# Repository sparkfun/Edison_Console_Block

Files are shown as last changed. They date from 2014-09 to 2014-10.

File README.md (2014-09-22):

Console
=====================

The Console expansion board delivers power to the Intel Edison while providing a simple console interface.  This is a minimal solution to get started using the Intel Edison.  The Console board can supply 4V and up to 1.5A of current to power the Edison and any other expansion boards you may add to your stack. This power is passed through the VSYS line of the Edison.

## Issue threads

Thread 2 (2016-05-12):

Where can I find BOM

Tondy, 2016-05-12:
Hello

Is the Bill of materials available on the github?

ToniCorinne, 2016-05-12:
We are not currently including BOMs as separate files in our repositories, though this is something we are looking into. Currently, you'd need to run the bom.ulp on the Eagle files to export the BOM. For more information on working with Eagle files, check out our tutorials [here](https://learn.sparkfun.com/tutorials/tags/eagle).

Closed 2016-05-12.

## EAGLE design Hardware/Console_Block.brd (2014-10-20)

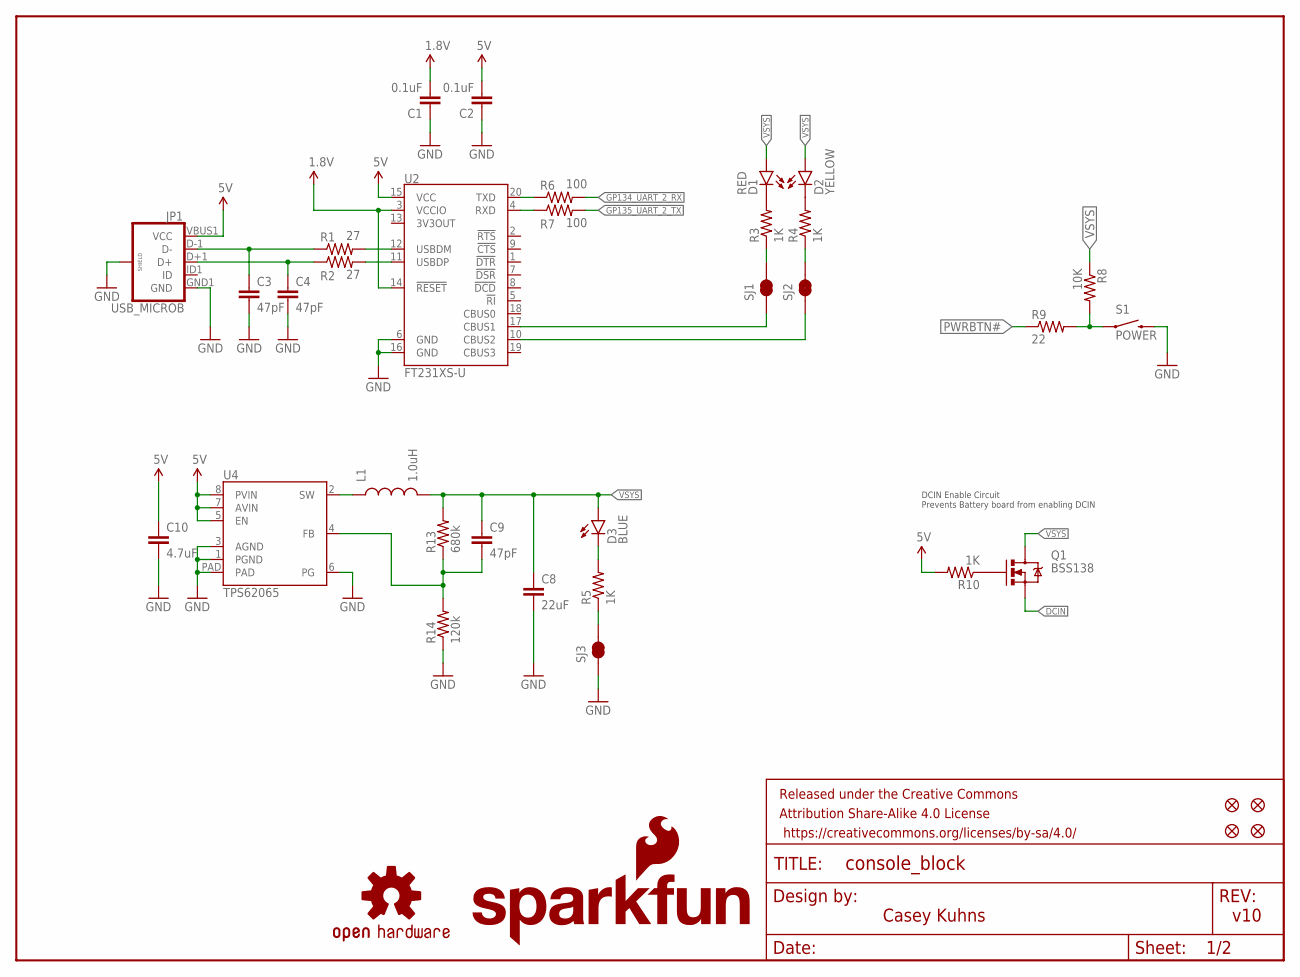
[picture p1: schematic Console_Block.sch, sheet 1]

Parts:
C1, C2: 0.1uF; 0603-CAP
C3, C4, C9: 47pF; 0603-CAP
C8: 22uF; 0805
C10: 4.7uF; 0603-CAP
D1: RED; LED-0603
D2: YELLOW; LED-0603
D3: BLUE; LED-0603
FID1, FID2, FID3, FID4: FIDUCIAL1X2; FIDUCIAL-1X2
FRAME1: FRAME-LETTER; CREATIVE_COMMONS
JP1: USB_MICROB; USB-B-MICRO-SMD_V03
L1: 1.0uH; INDUCTOR-SRP4020
LOGO1: SFE_LOGO_NAME_FLAME.1_INCH; SFE_LOGO_NAME_FLAME_.1
LOGO4: OSHW-LOGOS; OSHW-LOGO-S
Q1: BSS138; SOT23-3
R1, R2: 27; 0603
R3, R4, R5, R10: 1K; 0603-RES
R6, R7: 100; 0603-RES
R8: 10K; 0603-RES
R9: 22; 0603-RES
R13: 680k; 0603-RES
R14: 120k; 0603-RES
S1: POWER; TACTILE_SWITCH-SMD-RIGHT-ANGLE
SJ1, SJ2, SJ3: JUMPER-PAD-2-NC_BY_TRACE; PAD-JUMPER-2-NC_BY_TRACE_YES_SILK
U2: FT231XS-U; SSOP20_L
U4: TPS62065; WSON-8-PAD

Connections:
1.8V: C1.2, U2.3 (VCCIO), U2.14 (!RESET); also elsewhere on the board
5V: C2.2, C10.1, JP1.VBUS1 (VCC), R10.2, U2.15 (VCC), U4.5 (EN), U4.7 (AVIN), U4.8 (PVIN)
DCIN: Q1.2 (S); also elsewhere on the board
GND: C1.1, C2.1, C3.2, C4.2, C8.2, C10.2, JP1.GND1 (GND), JP1.SHIELD1 (SHIELD), JP1.SHIELD2 (SHIELD), JP1.SHIELD3 (SHIELD), R14.1, S1.2, SJ3.1, U2.6 (GND), U2.16 (GND), U4.1 (PGND), U4.3 (AGND), U4.6 (PG), U4.PAD; also elsewhere on the board
GP134_UART_2_RX: R6.2; also elsewhere on the board
GP135_UART_2_TX: R7.2; also elsewhere on the board
unnamed: SJ1.1, U2.17 (CBUS1)
unnamed: C3.1, JP1.D-1 (D-), R1.1
unnamed: C4.1, JP1.D+1 (D+), R2.1
unnamed: R1.2, U2.12 (USBDM)
unnamed: R2.2, U2.11 (USBDP)
unnamed: SJ2.1, U2.10 (CBUS2)
unnamed: R3.1, SJ1.2
unnamed: R4.1, SJ2.2
unnamed: D1.C, R3.2
unnamed: D2.C, R4.2
unnamed: R6.1, U2.20 (TXD)
unnamed: D3.C, R5.2
unnamed: R5.1, SJ3.2
unnamed: R7.1, U2.4 (RXD)
unnamed: R8.2, R9.2, S1.1
unnamed: Q1.1 (G), R10.1
unnamed: C9.2, R13.1, R14.2, U4.4 (FB)
unnamed: L1.P$1 (1), U4.2 (SW)
PWRBTN#: R9.1; also elsewhere on the board
VSYS: C8.1, C9.1, D1.A, D2.A, D3.A, L1.P$2 (2), Q1.3 (D), R8.1, R13.2; also elsewhere on the board

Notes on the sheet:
v10
Casey Kuhns
DCIN Enable Circuit Prevents Battery board from enabling DCIN

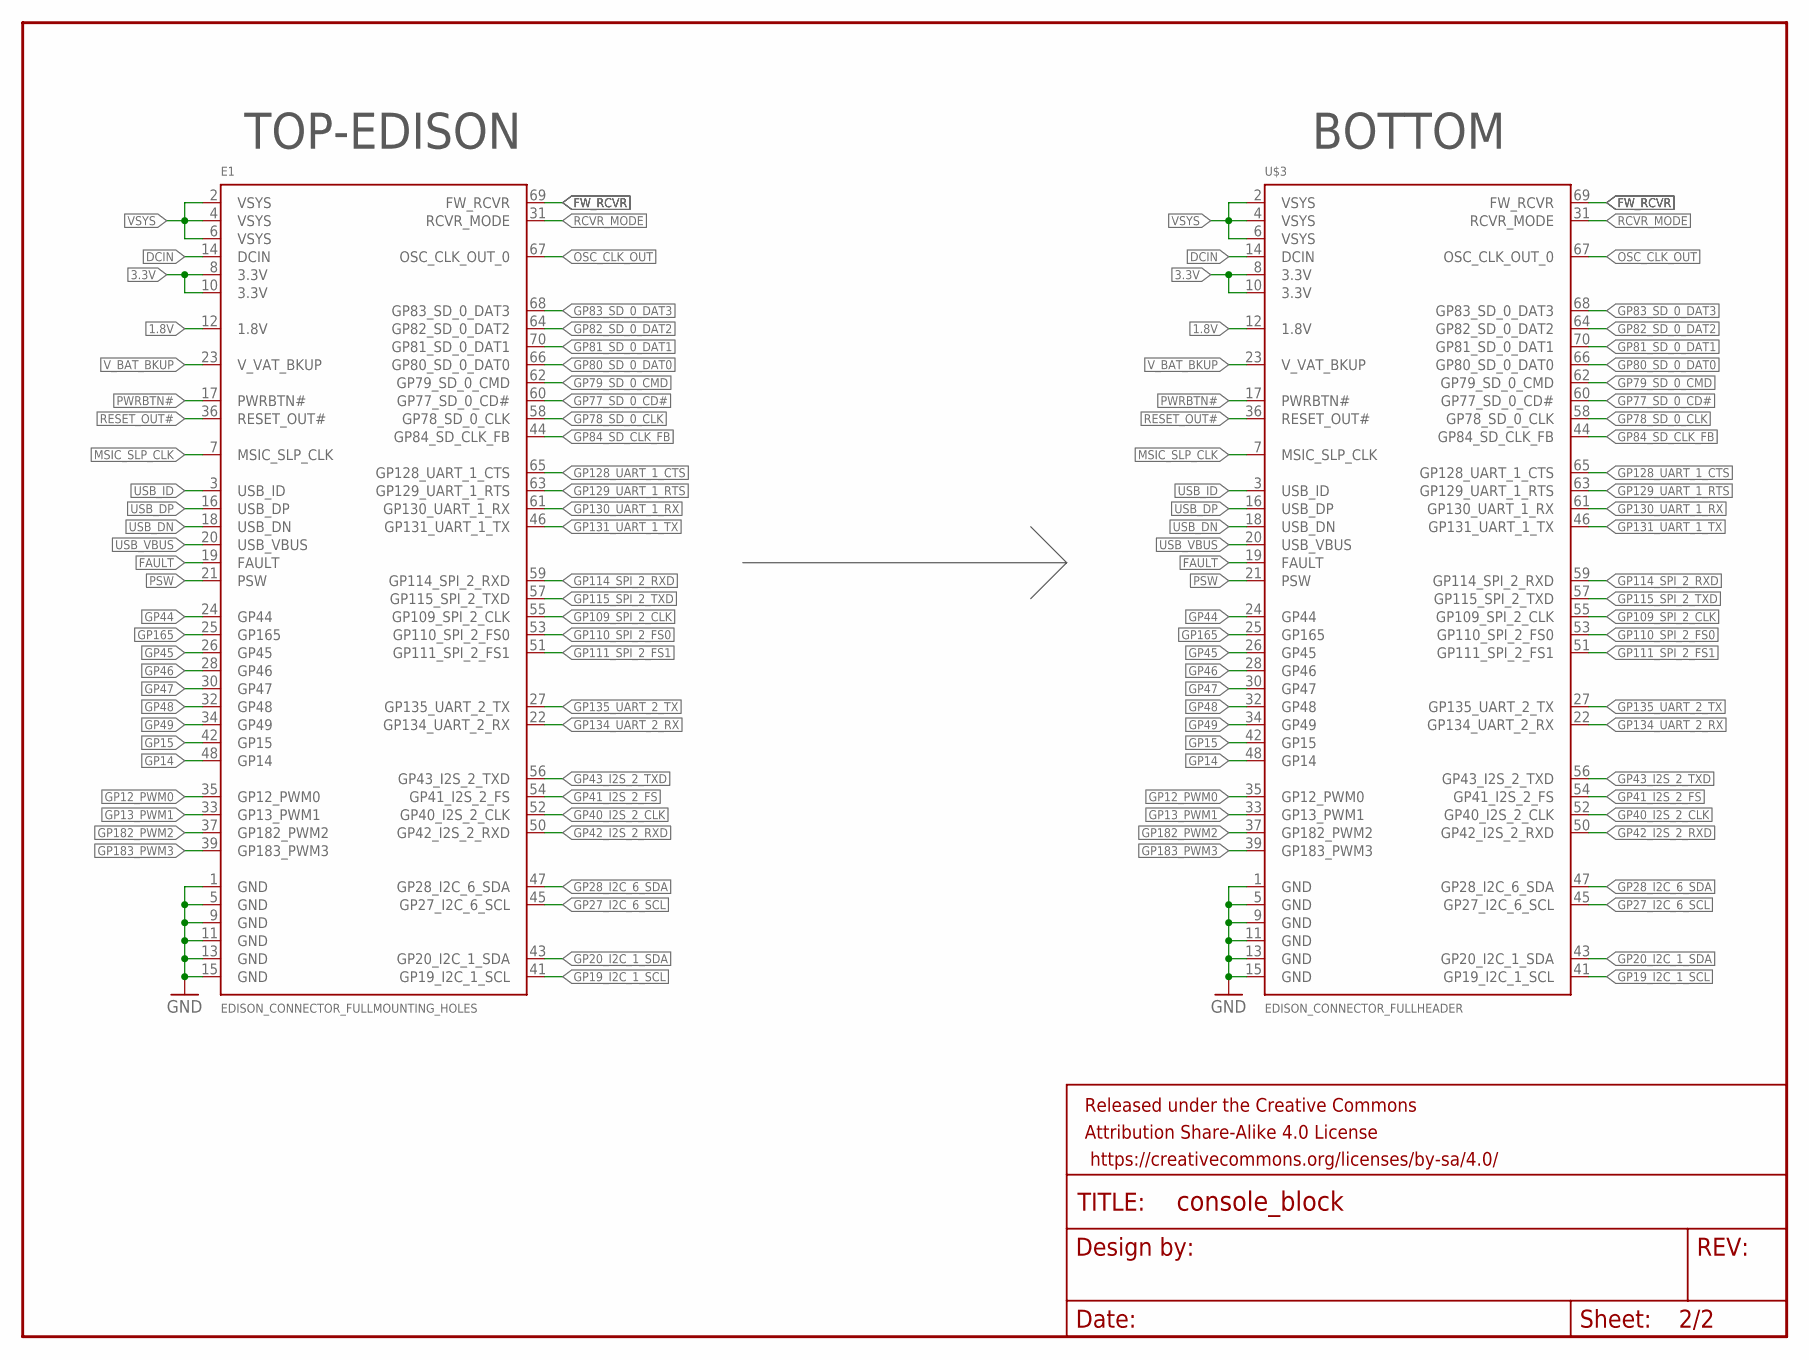
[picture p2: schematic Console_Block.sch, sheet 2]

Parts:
E1: EDISON_CONNECTOR_FULLMOUNTING_HOLES; EDISON_DAUGHTER
FRAME2: FRAME-LETTER; CREATIVE_COMMONS
U$3: EDISON_CONNECTOR_FULLHEADER; DF40C-70DP-0.4(51)

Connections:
1.8V: E1.12 (1.8V), U$3.12 (1.8V); also elsewhere on the board
3.3V: E1.8 (3.3V), E1.10 (3.3V), U$3.8 (3.3V), U$3.10 (3.3V)
DCIN: E1.14 (DCIN), U$3.14 (DCIN); also elsewhere on the board
FAULT: E1.19 (FAULT), U$3.19 (FAULT)
FW_RCVR: E1.69 (FW_RCVR), U$3.69 (FW_RCVR)
GND: E1.1 (GND), E1.5 (GND), E1.9 (GND), E1.11 (GND), E1.13 (GND), E1.15 (GND), U$3.1 (GND), U$3.5 (GND), U$3.9 (GND), U$3.11 (GND), U$3.13 (GND), U$3.15 (GND); also elsewhere on the board
GP12_PWM0: E1.35 (GP12_PWM0), U$3.35 (GP12_PWM0)
GP13_PWM1: E1.33 (GP13_PWM1), U$3.33 (GP13_PWM1)
GP14: E1.48 (GP14), U$3.48 (GP14)
GP15: E1.42 (GP15), U$3.42 (GP15)
GP19_I2C_1_SCL: E1.41 (GP19_I2C_1_SCL), U$3.41 (GP19_I2C_1_SCL)
GP20_I2C_1_SDA: E1.43 (GP20_I2C_1_SDA), U$3.43 (GP20_I2C_1_SDA)
GP27_I2C_6_SCL: E1.45 (GP27_I2C_6_SCL), U$3.45 (GP27_I2C_6_SCL)
GP28_I2C_6_SDA: E1.47 (GP28_I2C_6_SDA), U$3.47 (GP28_I2C_6_SDA)
GP40_I2S_2_CLK: E1.52 (GP40_I2S_2_CLK), U$3.52 (GP40_I2S_2_CLK)
GP41_I2S_2_FS: E1.54 (GP41_I2S_2_FS), U$3.54 (GP41_I2S_2_FS)
GP42_I2S_2_RXD: E1.50 (GP42_I2S_2_RXD), U$3.50 (GP42_I2S_2_RXD)
GP43_I2S_2_TXD: E1.56 (GP43_I2S_2_TXD), U$3.56 (GP43_I2S_2_TXD)
GP44: E1.24 (GP44), U$3.24 (GP44)
GP45: E1.26 (GP45), U$3.26 (GP45)
GP46: E1.28 (GP46), U$3.28 (GP46)
GP47: E1.30 (GP47), U$3.30 (GP47)
GP48: E1.32 (GP48), U$3.32 (GP48)
GP49: E1.34 (GP49), U$3.34 (GP49)
GP77_SD_0_CD#: E1.60 (GP77_SD_0_CD#), U$3.60 (GP77_SD_0_CD#)
GP78_SD_0_CLK: E1.58 (GP78_SD_0_CLK), U$3.58 (GP78_SD_0_CLK)
GP79_SD_0_CMD: E1.62 (GP79_SD_0_CMD), U$3.62 (GP79_SD_0_CMD)
GP80_SD_0_DAT0: E1.66 (GP80_SD_0_DAT0), U$3.66 (GP80_SD_0_DAT0)
GP81_SD_0_DAT1: E1.70 (GP81_SD_0_DAT1), U$3.70 (GP81_SD_0_DAT1)
GP82_SD_0_DAT2: E1.64 (GP82_SD_0_DAT2), U$3.64 (GP82_SD_0_DAT2)
GP83_SD_0_DAT3: E1.68 (GP83_SD_0_DAT3), U$3.68 (GP83_SD_0_DAT3)
GP84_SD_CLK_FB: E1.44 (GP84_SD_CLK_FB), U$3.44 (GP84_SD_CLK_FB)
GP109_SPI_2_CLK: E1.55 (GP109_SPI_2_CLK), U$3.55 (GP109_SPI_2_CLK)
GP110_SPI_2_FS0: E1.53 (GP110_SPI_2_FS0), U$3.53 (GP110_SPI_2_FS0)
GP111_SPI_2_FS1: E1.51 (GP111_SPI_2_FS1), U$3.51 (GP111_SPI_2_FS1)
GP114_SPI_2_RXD: E1.59 (GP114_SPI_2_RXD), U$3.59 (GP114_SPI_2_RXD)
GP115_SPI_2_TXD: E1.57 (GP115_SPI_2_TXD), U$3.57 (GP115_SPI_2_TXD)
GP128_UART_1_CTS: E1.65 (GP128_UART_1_CTS), U$3.65 (GP128_UART_1_CTS)
GP129_UART_1_RTS: E1.63 (GP129_UART_1_RTS), U$3.63 (GP129_UART_1_RTS)
GP130_UART_1_RX: E1.61 (GP130_UART_1_RX), U$3.61 (GP130_UART_1_RX)
GP131_UART_1_TX: E1.46 (GP131_UART_1_TX), U$3.46 (GP131_UART_1_TX)
GP134_UART_2_RX: E1.22 (GP134_UART_2_RX), U$3.22 (GP134_UART_2_RX); also elsewhere on the board
GP135_UART_2_TX: E1.27 (GP135_UART_2_TX), U$3.27 (GP135_UART_2_TX); also elsewhere on the board
GP165: E1.25 (GP165), U$3.25 (GP165)
GP182_PWM2: E1.37 (GP182_PWM2), U$3.37 (GP182_PWM2)
GP183_PWM3: E1.39 (GP183_PWM3), U$3.39 (GP183_PWM3)
MSIC_SLP_CLK: E1.7 (MSIC_SLP_CLK), U$3.7 (MSIC_SLP_CLK)
OSC_CLK_OUT: E1.67 (OSC_CLK_OUT_0), U$3.67 (OSC_CLK_OUT_0)
PSW: E1.21 (PSW), U$3.21 (PSW)
PWRBTN#: E1.17 (PWRBTN#), U$3.17 (PWRBTN#); also elsewhere on the board
RCVR_MODE: E1.31 (RCVR_MODE), U$3.31 (RCVR_MODE)
RESET_OUT#: E1.36 (RESET_OUT#), U$3.36 (RESET_OUT#)
USB_DN: E1.18 (USB_DN), U$3.18 (USB_DN)
USB_DP: E1.16 (USB_DP), U$3.16 (USB_DP)
USB_ID: E1.3 (USB_ID), U$3.3 (USB_ID)
USB_VBUS: E1.20 (USB_VBUS), U$3.20 (USB_VBUS)
VSYS: E1.2 (VSYS), E1.4 (VSYS), E1.6 (VSYS), U$3.2 (VSYS), U$3.4 (VSYS), U$3.6 (VSYS); also elsewhere on the board
V_BAT_BKUP: E1.23 (V_VAT_BKUP), U$3.23 (V_VAT_BKUP)

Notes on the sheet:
TOP-EDISON
BOTTOM

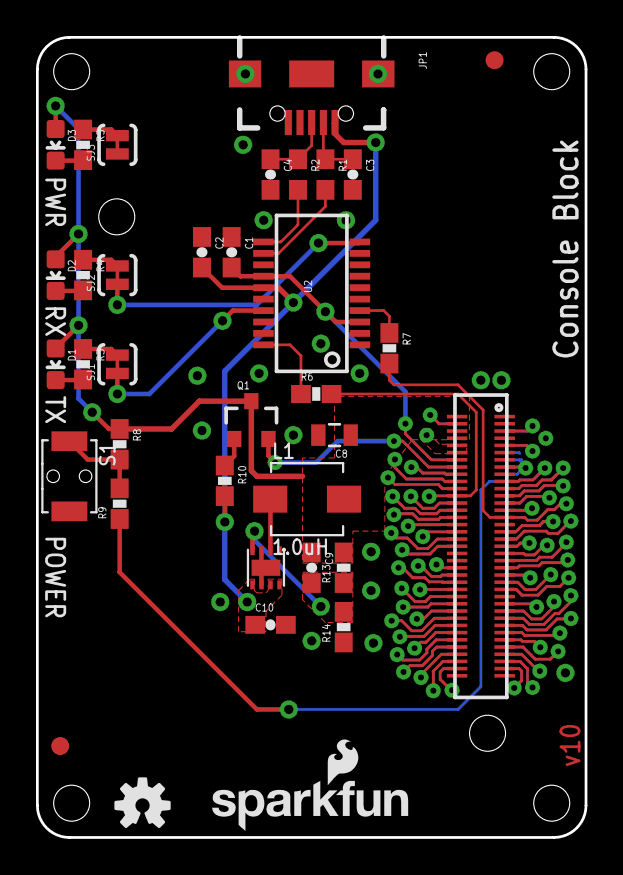
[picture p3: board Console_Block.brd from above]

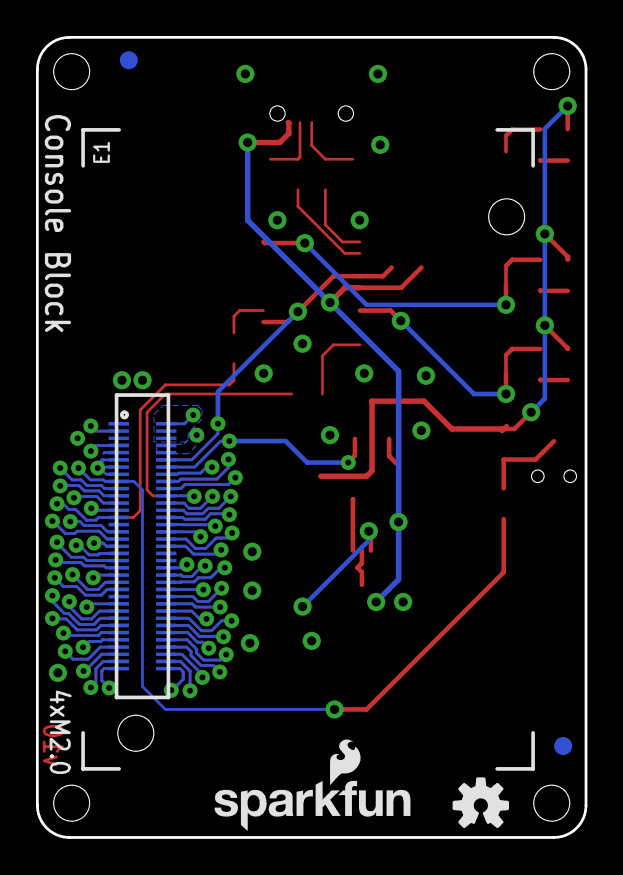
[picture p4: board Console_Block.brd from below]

Board: 2 copper layers, 30.5 x 44.5 mm, 43 parts (6 on the bottom side), 77 nets.

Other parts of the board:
LOGO2: OSHW-LOGOS; OSHW-LOGO-S
LOGO3: SFE_LOGO_NAME_FLAME.1_INCH; SFE_LOGO_NAME_FLAME_.1

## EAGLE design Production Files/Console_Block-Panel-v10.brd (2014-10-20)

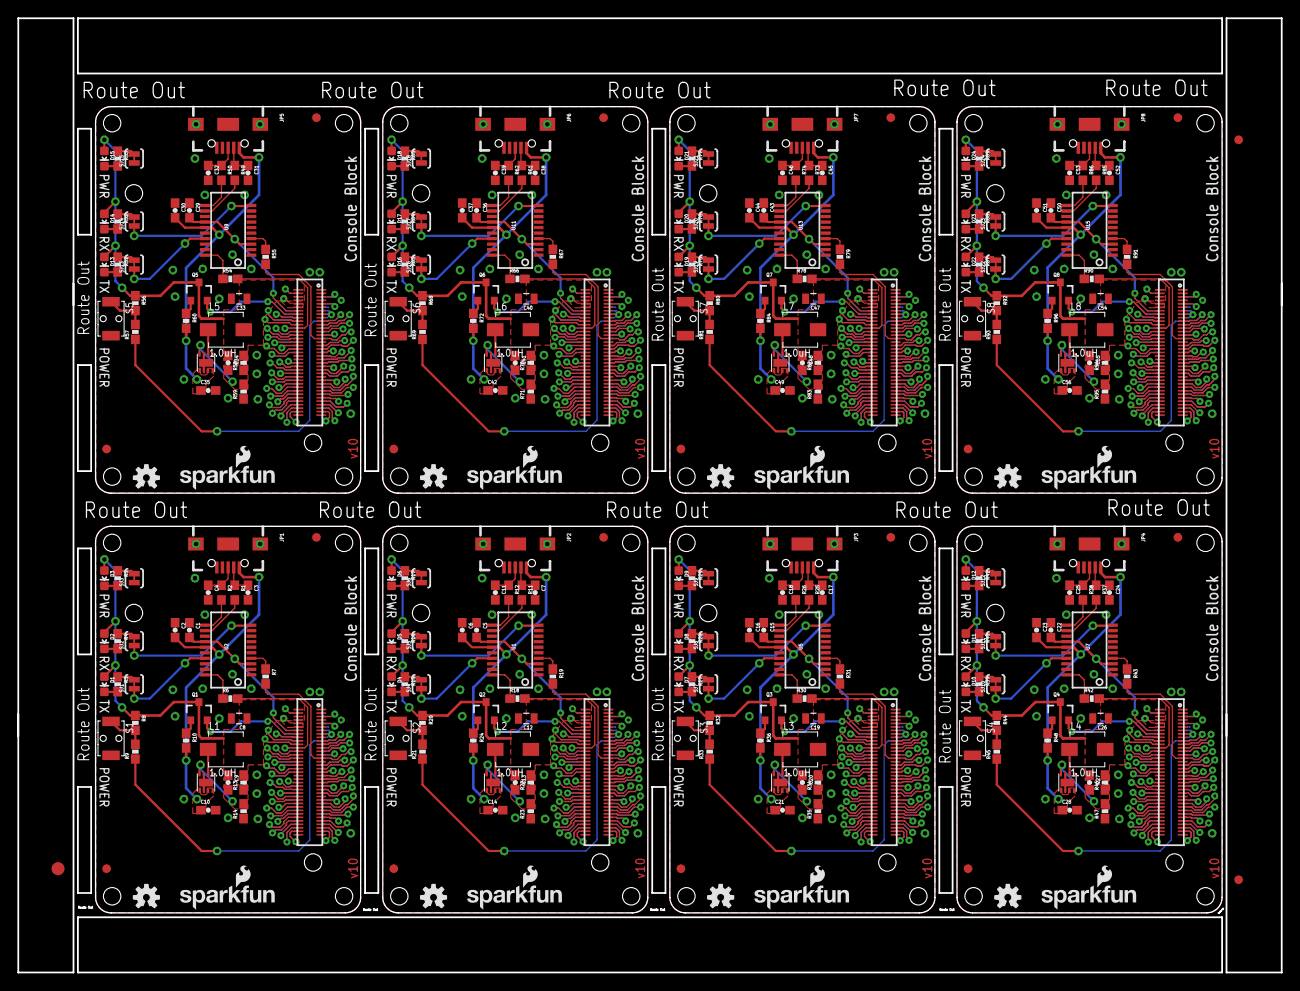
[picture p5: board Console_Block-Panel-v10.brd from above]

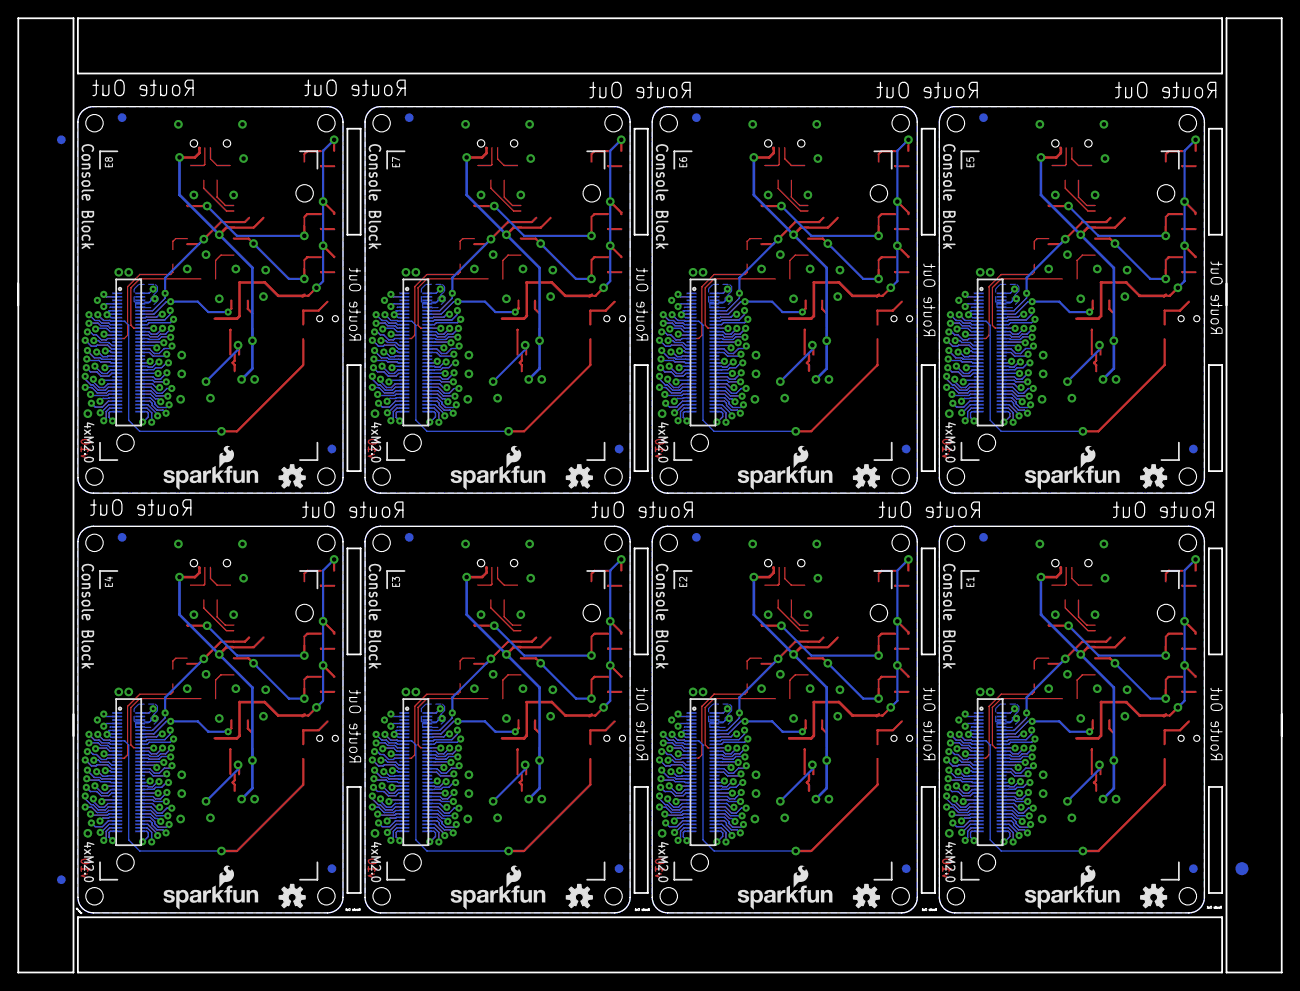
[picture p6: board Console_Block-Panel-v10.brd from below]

Board: 2 copper layers, 145.3 x 109.7 mm, 334 parts (51 on the bottom side), 616 nets.

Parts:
C1, C2, C5, C6, C15, C16, C22, C23, C29, C30, C36, C37, C43, C44, C50, C51: 0.1uF; 0603-CAP
C3, C4, C7, C9, C11, C13, C17, C18, C20, C24, C25, C27, C31, C32, C34, C38, C39, C41, C45, C46, C48, C52, C53, C55: 47pF; 0603-CAP
C8, C12, C19, C26, C33, C40, C47, C54: 22uF; 0805
C10, C14, C21, C28, C35, C42, C49, C56: 4.7uF; 0603-CAP
D1, D4, D7, D10, D13, D16, D19, D22: RED; LED-0603
D2, D5, D8, D11, D14, D17, D20, D23: YELLOW; LED-0603
D3, D6, D9, D12, D15, D18, D21, D24: BLUE; LED-0603
E1, E2, E3, E4, E5, E6, E7, E8: EDISON_CONNECTOR_FULLMOUNTING_HOLES; EDISON_DAUGHTER
E$1, E$2: FIDUCIAL-1.5X3
E$3, E$4, E$5, E$6: FIDUCIAL-1X2
FID1, FID2, FID3, FID4, FID5, FID6, FID7, FID8, FID9, FID10, FID11, FID12, FID13, FID14, FID15, FID16, FID17, FID18, FID19, FID20, FID21, FID22, FID23, FID24, FID25, FID26, FID27, FID28, FID29, FID30, FID31, FID32: FIDUCIAL1X2; FIDUCIAL-1X2
JP1, JP2, JP3, JP4, JP5, JP6, JP7, JP8: USB_MICROB; USB-B-MICRO-SMD_V03
L1, L2, L3, L4, L5, L6, L7, L8: 1.0uH; INDUCTOR-SRP4020
LOGO1, LOGO3, LOGO6, LOGO7, LOGO10, LOGO11, LOGO14, LOGO15, LOGO18, LOGO19, LOGO22, LOGO23, LOGO26, LOGO27, LOGO30, LOGO31: SFE_LOGO_NAME_FLAME.1_INCH; SFE_LOGO_NAME_FLAME_.1
LOGO2, LOGO4, LOGO5, LOGO8, LOGO9, LOGO12, LOGO13, LOGO16, LOGO17, LOGO20, LOGO21, LOGO24, LOGO25, LOGO28, LOGO29, LOGO32: OSHW-LOGOS; OSHW-LOGO-S
Q1, Q2, Q3, Q4, Q5, Q6, Q7, Q8: BSS138; SOT23-3
R1, R2, R11, R12, R25, R26, R37, R38, R49, R50, R61, R62, R73, R74, R85, R86: 27; 0603
R3, R4, R5, R10, R15, R16, R17, R24, R27, R28, R29, R36, R39, R40, R41, R48, R51, R52, R53, R60, R63, R64, R65, R72, R75, R76, R77, R84, R87, R88, R89, R96: 1K; 0603-RES
R6, R7, R18, R19, R30, R31, R42, R43, R54, R55, R66, R67, R78, R79, R90, R91: 100; 0603-RES
R8, R20, R32, R44, R56, R68, R80, R92: 10K; 0603-RES
R9, R21, R33, R45, R57, R69, R81, R93: 22; 0603-RES
R13, R22, R34, R46, R58, R70, R82, R94: 680k; 0603-RES
R14, R23, R35, R47, R59, R71, R83, R95: 120k; 0603-RES
S1, S2, S3, S4, S5, S6, S7, S8: POWER; TACTILE_SWITCH-SMD-RIGHT-ANGLE
SJ1, SJ2, SJ3, SJ4, SJ5, SJ6, SJ7, SJ8, SJ9, SJ10, SJ11, SJ12, SJ13, SJ14, SJ15, SJ16, SJ17, SJ18, SJ19, SJ20, SJ21, SJ22, SJ23, SJ24: JUMPER-PAD-2-NC_BY_TRACE; PAD-JUMPER-2-NC_BY_TRACE_YES_SILK
U1, U2, U5, U7, U9, U11, U13, U15: FT231XS-U; SSOP20_L
U3, U4, U6, U8, U10, U12, U14, U16: TPS62065; WSON-8-PAD
U$1, U$2, U$3, U$4, U$5, U$6, U$7, U$8: EDISON_CONNECTOR_FULLHEADER; DF40C-70DP-0.4(51)

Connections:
1.8V: C1.2, E1.12, U2.3, U2.14, U$3.12
1.8V1: C5.2, E2.12, U1.3, U1.14, U$1.12
1.8V2: C15.2, E3.12, U5.3, U5.14, U$2.12
1.8V3: C22.2, E4.12, U7.3, U7.14, U$4.12
1.8V4: C29.2, E5.12, U9.3, U9.14, U$5.12
1.8V5: C36.2, E6.12, U11.3, U11.14, U$6.12
1.8V6: C43.2, E7.12, U13.3, U13.14, U$7.12
1.8V7: C50.2, E8.12, U15.3, U15.14, U$8.12
3.3V: E1.8, E1.10, U$3.8, U$3.10
3.3V1: E2.8, E2.10, U$1.8, U$1.10
3.3V2: E3.8, E3.10, U$2.8, U$2.10
3.3V3: E4.8, E4.10, U$4.8, U$4.10
3.3V4: E5.8, E5.10, U$5.8, U$5.10
3.3V5: E6.8, E6.10, U$6.8, U$6.10
3.3V6: E7.8, E7.10, U$7.8, U$7.10
3.3V7: E8.8, E8.10, U$8.8, U$8.10
5V: C2.2, C10.1, JP1.VBUS1, R10.2, U2.15, U4.5, U4.7, U4.8
5V1: C6.2, C14.1, JP2.VBUS1, R24.2, U1.15, U3.5, U3.7, U3.8
5V2: C16.2, C21.1, JP3.VBUS1, R36.2, U5.15, U6.5, U6.7, U6.8
5V3: C23.2, C28.1, JP4.VBUS1, R48.2, U7.15, U8.5, U8.7, U8.8
5V4: C30.2, C35.1, JP5.VBUS1, R60.2, U9.15, U10.5, U10.7, U10.8
5V5: C37.2, C42.1, JP6.VBUS1, R72.2, U11.15, U12.5, U12.7, U12.8
5V6: C44.2, C49.1, JP7.VBUS1, R84.2, U13.15, U14.5, U14.7, U14.8
5V7: C51.2, C56.1, JP8.VBUS1, R96.2, U15.15, U16.5, U16.7, U16.8
DCIN: E1.14, Q1.2, U$3.14
DCIN1: E2.14, Q2.2, U$1.14
DCIN2: E3.14, Q3.2, U$2.14
DCIN3: E4.14, Q4.2, U$4.14
DCIN4: E5.14, Q5.2, U$5.14
DCIN5: E6.14, Q6.2, U$6.14
DCIN6: E7.14, Q7.2, U$7.14
DCIN7: E8.14, Q8.2, U$8.14
FAULT: E1.19, U$3.19
FAULT1: E2.19, U$1.19
FAULT2: E3.19, U$2.19
FAULT3: E4.19, U$4.19
FAULT4: E5.19, U$5.19
FAULT5: E6.19, U$6.19
FAULT6: E7.19, U$7.19
FAULT7: E8.19, U$8.19
FW_RCVR: E1.69, U$3.69
FW_RCVR1: E2.69, U$1.69
FW_RCVR2: E3.69, U$2.69
FW_RCVR3: E4.69, U$4.69
FW_RCVR4: E5.69, U$5.69
FW_RCVR5: E6.69, U$6.69
FW_RCVR6: E7.69, U$7.69
FW_RCVR7: E8.69, U$8.69
GND: C1.1, C2.1, C3.2, C4.2, C8.2, C10.2, E1.1, E1.5, E1.9, E1.11, E1.13, E1.15, JP1.GND1, JP1.SHIELD1, JP1.SHIELD2, JP1.SHIELD3, R14.1, S1.2, SJ3.1, U2.6, U2.16, U4.1, U4.3, U4.6, U4.PAD, U$3.1, U$3.5, U$3.9, U$3.11, U$3.13, U$3.15
GND1: C5.1, C6.1, C7.2, C11.2, C12.2, C14.2, E2.1, E2.5, E2.9, E2.11, E2.13, E2.15, JP2.GND1, JP2.SHIELD1, JP2.SHIELD2, JP2.SHIELD3, R23.1, S2.2, SJ6.1, U1.6, U1.16, U3.1, U3.3, U3.6, U3.PAD, U$1.1, U$1.5, U$1.9, U$1.11, U$1.13, U$1.15
GND2: C15.1, C16.1, C17.2, C18.2, C19.2, C21.2, E3.1, E3.5, E3.9, E3.11, E3.13, E3.15, JP3.GND1, JP3.SHIELD1, JP3.SHIELD2, JP3.SHIELD3, R35.1, S3.2, SJ9.1, U5.6, U5.16, U6.1, U6.3, U6.6, U6.PAD, U$2.1, U$2.5, U$2.9, U$2.11, U$2.13, U$2.15
GND3: C22.1, C23.1, C24.2, C25.2, C26.2, C28.2, E4.1, E4.5, E4.9, E4.11, E4.13, E4.15, JP4.GND1, JP4.SHIELD1, JP4.SHIELD2, JP4.SHIELD3, R47.1, S4.2, SJ12.1, U7.6, U7.16, U8.1, U8.3, U8.6, U8.PAD, U$4.1, U$4.5, U$4.9, U$4.11, U$4.13, U$4.15
GND4: C29.1, C30.1, C31.2, C32.2, C33.2, C35.2, E5.1, E5.5, E5.9, E5.11, E5.13, E5.15, JP5.GND1, JP5.SHIELD1, JP5.SHIELD2, JP5.SHIELD3, R59.1, S5.2, SJ15.1, U9.6, U9.16, U10.1, U10.3, U10.6, U10.PAD, U$5.1, U$5.5, U$5.9, U$5.11, U$5.13, U$5.15
GND5: C36.1, C37.1, C38.2, C39.2, C40.2, C42.2, E6.1, E6.5, E6.9, E6.11, E6.13, E6.15, JP6.GND1, JP6.SHIELD1, JP6.SHIELD2, JP6.SHIELD3, R71.1, S6.2, SJ18.1, U11.6, U11.16, U12.1, U12.3, U12.6, U12.PAD, U$6.1, U$6.5, U$6.9, U$6.11, U$6.13, U$6.15
GND6: C43.1, C44.1, C45.2, C46.2, C47.2, C49.2, E7.1, E7.5, E7.9, E7.11, E7.13, E7.15, JP7.GND1, JP7.SHIELD1, JP7.SHIELD2, JP7.SHIELD3, R83.1, S7.2, SJ21.1, U13.6, U13.16, U14.1, U14.3, U14.6, U14.PAD, U$7.1, U$7.5, U$7.9, U$7.11, U$7.13, U$7.15
GND7: C50.1, C51.1, C52.2, C53.2, C54.2, C56.2, E8.1, E8.5, E8.9, E8.11, E8.13, E8.15, JP8.GND1, JP8.SHIELD1, JP8.SHIELD2, JP8.SHIELD3, R95.1, S8.2, SJ24.1, U15.6, U15.16, U16.1, U16.3, U16.6, U16.PAD, U$8.1, U$8.5, U$8.9, U$8.11, U$8.13, U$8.15
GP1: E2.48, U$1.48
GP2: E2.42, U$1.42
GP3: E2.34, U$1.34
GP4: E2.32, U$1.32
GP5: E2.30, U$1.30
GP6: E2.28, U$1.28
GP7: E2.26, U$1.26
GP8: E2.25, U$1.25
GP9: E2.24, U$1.24
GP10: E3.48, U$2.48
GP11: E3.42, U$2.42
GP12: E3.34, U$2.34
GP12_PWM0: E1.35, U$3.35
GP12_PWM1: E2.35, U$1.35
GP12_PWM2: E3.35, U$2.35
GP12_PWM3: E4.35, U$4.35
GP12_PWM4: E5.35, U$5.35
GP12_PWM5: E6.35, U$6.35
GP12_PWM6: E7.35, U$7.35
GP12_PWM7: E8.35, U$8.35
GP13: E3.32, U$2.32
GP13_PWM1: E1.33, U$3.33
GP13_PWM2: E2.33, U$1.33
GP13_PWM3: E3.33, U$2.33
GP13_PWM4: E4.33, U$4.33
GP13_PWM5: E5.33, U$5.33
GP13_PWM6: E6.33, U$6.33
GP13_PWM7: E7.33, U$7.33
GP13_PWM8: E8.33, U$8.33
GP14: E1.48, U$3.48
GP15: E1.42, U$3.42
GP16: E3.30, U$2.30
GP17: E3.28, U$2.28
GP18: E3.26, U$2.26
GP19: E3.25, U$2.25
GP19_I2C_1_SCL: E1.41, U$3.41
GP19_I2C_1_SCL1: E2.41, U$1.41
GP19_I2C_1_SCL2: E3.41, U$2.41
GP19_I2C_1_SCL3: E4.41, U$4.41
GP19_I2C_1_SCL4: E5.41, U$5.41
GP19_I2C_1_SCL5: E6.41, U$6.41
GP19_I2C_1_SCL6: E7.41, U$7.41
GP19_I2C_1_SCL7: E8.41, U$8.41
GP20: E3.24, U$2.24
GP20_I2C_1_SDA: E1.43, U$3.43
GP20_I2C_1_SDA1: E2.43, U$1.43
GP20_I2C_1_SDA2: E3.43, U$2.43
GP20_I2C_1_SDA3: E4.43, U$4.43
GP20_I2C_1_SDA4: E5.43, U$5.43
GP20_I2C_1_SDA5: E6.43, U$6.43
GP20_I2C_1_SDA6: E7.43, U$7.43
GP20_I2C_1_SDA7: E8.43, U$8.43
GP21: E4.48, U$4.48
GP22: E4.42, U$4.42
GP23: E4.34, U$4.34
GP24: E4.32, U$4.32
GP25: E4.30, U$4.30
GP26: E4.28, U$4.28
GP27: E4.26, U$4.26
GP27_I2C_6_SCL: E1.45, U$3.45
GP27_I2C_6_SCL1: E2.45, U$1.45
GP27_I2C_6_SCL2: E3.45, U$2.45
GP27_I2C_6_SCL3: E4.45, U$4.45
GP27_I2C_6_SCL4: E5.45, U$5.45
GP27_I2C_6_SCL5: E6.45, U$6.45
GP27_I2C_6_SCL6: E7.45, U$7.45
GP27_I2C_6_SCL7: E8.45, U$8.45
GP28: E4.25, U$4.25
GP28_I2C_6_SDA: E1.47, U$3.47
GP28_I2C_6_SDA1: E2.47, U$1.47
GP28_I2C_6_SDA2: E3.47, U$2.47
GP28_I2C_6_SDA3: E4.47, U$4.47
GP28_I2C_6_SDA4: E5.47, U$5.47
GP28_I2C_6_SDA5: E6.47, U$6.47
GP28_I2C_6_SDA6: E7.47, U$7.47
GP28_I2C_6_SDA7: E8.47, U$8.47
GP29: E4.24, U$4.24
GP30: E5.48, U$5.48
GP31: E5.42, U$5.42
GP32: E5.34, U$5.34
GP33: E5.32, U$5.32
GP34: E5.30, U$5.30
GP35: E5.28, U$5.28
GP36: E5.26, U$5.26
GP37: E5.25, U$5.25
GP38: E5.24, U$5.24
GP39: E6.48, U$6.48
GP40: E6.42, U$6.42
GP40_I2S_2_CLK: E1.52, U$3.52
GP40_I2S_2_CLK1: E2.52, U$1.52
GP40_I2S_2_CLK2: E3.52, U$2.52
GP40_I2S_2_CLK3: E4.52, U$4.52
GP40_I2S_2_CLK4: E5.52, U$5.52
GP40_I2S_2_CLK5: E6.52, U$6.52
GP40_I2S_2_CLK6: E7.52, U$7.52
GP40_I2S_2_CLK7: E8.52, U$8.52
GP41: E6.34, U$6.34
GP41_I2S_2_FS: E1.54, U$3.54
GP41_I2S_2_FS1: E2.54, U$1.54
GP41_I2S_2_FS2: E3.54, U$2.54
GP41_I2S_2_FS3: E4.54, U$4.54
GP41_I2S_2_FS4: E5.54, U$5.54
GP41_I2S_2_FS5: E6.54, U$6.54
GP41_I2S_2_FS6: E7.54, U$7.54
GP41_I2S_2_FS7: E8.54, U$8.54
GP42: E6.32, U$6.32
GP42_I2S_2_RXD: E1.50, U$3.50
GP42_I2S_2_RXD1: E2.50, U$1.50
GP42_I2S_2_RXD2: E3.50, U$2.50
GP42_I2S_2_RXD3: E4.50, U$4.50
GP42_I2S_2_RXD4: E5.50, U$5.50
GP42_I2S_2_RXD5: E6.50, U$6.50
GP42_I2S_2_RXD6: E7.50, U$7.50
GP42_I2S_2_RXD7: E8.50, U$8.50
GP43: E6.30, U$6.30
GP43_I2S_2_TXD: E1.56, U$3.56
GP43_I2S_2_TXD1: E2.56, U$1.56
GP43_I2S_2_TXD2: E3.56, U$2.56
GP43_I2S_2_TXD3: E4.56, U$4.56
GP43_I2S_2_TXD4: E5.56, U$5.56
GP43_I2S_2_TXD5: E6.56, U$6.56
GP43_I2S_2_TXD6: E7.56, U$7.56
GP43_I2S_2_TXD7: E8.56, U$8.56
GP44: E1.24, U$3.24
GP45: E1.26, U$3.26
GP46: E1.28, U$3.28
GP47: E1.30, U$3.30
GP48: E1.32, U$3.32
GP49: E1.34, U$3.34
GP50: E6.28, U$6.28
GP51: E6.26, U$6.26
GP52: E6.25, U$6.25
GP53: E6.24, U$6.24
GP54: E7.48, U$7.48
GP55: E7.42, U$7.42
GP56: E7.34, U$7.34
GP57: E7.32, U$7.32
GP58: E7.30, U$7.30
GP59: E7.28, U$7.28
GP60: E7.26, U$7.26
GP61: E7.25, U$7.25
GP62: E7.24, U$7.24
GP63: E8.48, U$8.48
GP64: E8.42, U$8.42
GP65: E8.34, U$8.34
GP66: E8.32, U$8.32
GP67: E8.30, U$8.30
GP68: E8.28, U$8.28
GP69: E8.26, U$8.26
GP70: E8.25, U$8.25
GP71: E8.24, U$8.24
GP77_SD_0_CD#: E1.60, U$3.60
GP77_SD_0_CD#1: E2.60, U$1.60
GP77_SD_0_CD#2: E3.60, U$2.60
GP77_SD_0_CD#3: E4.60, U$4.60
GP77_SD_0_CD#4: E5.60, U$5.60
GP77_SD_0_CD#5: E6.60, U$6.60
GP77_SD_0_CD#6: E7.60, U$7.60
GP77_SD_0_CD#7: E8.60, U$8.60
GP78_SD_0_CLK: E1.58, U$3.58
GP78_SD_0_CLK1: E2.58, U$1.58
GP78_SD_0_CLK2: E3.58, U$2.58
GP78_SD_0_CLK3: E4.58, U$4.58
GP78_SD_0_CLK4: E5.58, U$5.58
GP78_SD_0_CLK5: E6.58, U$6.58
GP78_SD_0_CLK6: E7.58, U$7.58
GP78_SD_0_CLK7: E8.58, U$8.58
GP79_SD_0_CMD: E1.62, U$3.62
GP79_SD_0_CMD1: E2.62, U$1.62
GP79_SD_0_CMD2: E3.62, U$2.62
GP79_SD_0_CMD3: E4.62, U$4.62
GP79_SD_0_CMD4: E5.62, U$5.62
GP79_SD_0_CMD5: E6.62, U$6.62
GP79_SD_0_CMD6: E7.62, U$7.62
GP79_SD_0_CMD7: E8.62, U$8.62
GP80_SD_0_DAT0: E1.66, U$3.66
GP80_SD_0_DAT1: E2.66, U$1.66
GP80_SD_0_DAT2: E3.66, U$2.66
GP80_SD_0_DAT3: E4.66, U$4.66
GP80_SD_0_DAT4: E5.66, U$5.66
GP80_SD_0_DAT5: E6.66, U$6.66
GP80_SD_0_DAT6: E7.66, U$7.66
GP80_SD_0_DAT7: E8.66, U$8.66
GP81_SD_0_DAT1: E1.70, U$3.70
GP81_SD_0_DAT2: E2.70, U$1.70
GP81_SD_0_DAT3: E3.70, U$2.70
GP81_SD_0_DAT4: E4.70, U$4.70
GP81_SD_0_DAT5: E5.70, U$5.70
GP81_SD_0_DAT6: E6.70, U$6.70
GP81_SD_0_DAT7: E7.70, U$7.70
GP81_SD_0_DAT8: E8.70, U$8.70
GP82_SD_0_DAT1: E2.64, U$1.64
GP82_SD_0_DAT2: E1.64, U$3.64
GP82_SD_0_DAT3: E3.64, U$2.64
GP82_SD_0_DAT4: E4.64, U$4.64
GP82_SD_0_DAT5: E5.64, U$5.64
GP82_SD_0_DAT6: E6.64, U$6.64
GP82_SD_0_DAT7: E7.64, U$7.64
GP82_SD_0_DAT8: E8.64, U$8.64
GP83_SD_0_DAT1: E2.68, U$1.68
GP83_SD_0_DAT2: E3.68, U$2.68
GP83_SD_0_DAT3: E1.68, U$3.68
GP83_SD_0_DAT4: E4.68, U$4.68
GP83_SD_0_DAT5: E5.68, U$5.68
GP83_SD_0_DAT6: E6.68, U$6.68
GP83_SD_0_DAT7: E7.68, U$7.68
GP83_SD_0_DAT8: E8.68, U$8.68
GP84_SD_CLK_FB: E1.44, U$3.44
GP84_SD_CLK_FB1: E2.44, U$1.44
GP84_SD_CLK_FB2: E3.44, U$2.44
GP84_SD_CLK_FB3: E4.44, U$4.44
GP84_SD_CLK_FB4: E5.44, U$5.44
GP84_SD_CLK_FB5: E6.44, U$6.44
GP84_SD_CLK_FB6: E7.44, U$7.44
GP84_SD_CLK_FB7: E8.44, U$8.44
GP109_SPI_2_CLK: E1.55, U$3.55
GP109_SPI_2_CLK1: E2.55, U$1.55
GP109_SPI_2_CLK2: E3.55, U$2.55
GP109_SPI_2_CLK3: E4.55, U$4.55
GP109_SPI_2_CLK4: E5.55, U$5.55
GP109_SPI_2_CLK5: E6.55, U$6.55
GP109_SPI_2_CLK6: E7.55, U$7.55
GP109_SPI_2_CLK7: E8.55, U$8.55
GP110_SPI_2_FS0: E1.53, U$3.53
GP110_SPI_2_FS1: E2.53, U$1.53
GP110_SPI_2_FS2: E3.53, U$2.53
GP110_SPI_2_FS3: E4.53, U$4.53
GP110_SPI_2_FS4: E5.53, U$5.53
GP110_SPI_2_FS5: E6.53, U$6.53
GP110_SPI_2_FS6: E7.53, U$7.53
GP110_SPI_2_FS7: E8.53, U$8.53
GP111_SPI_2_FS1: E1.51, U$3.51
GP111_SPI_2_FS2: E2.51, U$1.51
GP111_SPI_2_FS3: E3.51, U$2.51
GP111_SPI_2_FS4: E4.51, U$4.51
GP111_SPI_2_FS5: E5.51, U$5.51
GP111_SPI_2_FS6: E6.51, U$6.51
GP111_SPI_2_FS7: E7.51, U$7.51
GP111_SPI_2_FS8: E8.51, U$8.51
GP114_SPI_2_RXD: E1.59, U$3.59
GP114_SPI_2_RXD1: E2.59, U$1.59
GP114_SPI_2_RXD2: E3.59, U$2.59
GP114_SPI_2_RXD3: E4.59, U$4.59
GP114_SPI_2_RXD4: E5.59, U$5.59
GP114_SPI_2_RXD5: E6.59, U$6.59
GP114_SPI_2_RXD6: E7.59, U$7.59
GP114_SPI_2_RXD7: E8.59, U$8.59
GP115_SPI_2_TXD: E1.57, U$3.57
GP115_SPI_2_TXD1: E2.57, U$1.57
GP115_SPI_2_TXD2: E3.57, U$2.57
GP115_SPI_2_TXD3: E4.57, U$4.57
GP115_SPI_2_TXD4: E5.57, U$5.57
GP115_SPI_2_TXD5: E6.57, U$6.57
GP115_SPI_2_TXD6: E7.57, U$7.57
GP115_SPI_2_TXD7: E8.57, U$8.57
GP128_UART_1_CTS: E1.65, U$3.65
GP128_UART_1_CTS1: E2.65, U$1.65
GP128_UART_1_CTS2: E3.65, U$2.65
GP128_UART_1_CTS3: E4.65, U$4.65
GP128_UART_1_CTS4: E5.65, U$5.65
GP128_UART_1_CTS5: E6.65, U$6.65
GP128_UART_1_CTS6: E7.65, U$7.65
GP128_UART_1_CTS7: E8.65, U$8.65
GP129_UART_1_RTS: E1.63, U$3.63
GP129_UART_1_RTS1: E2.63, U$1.63
GP129_UART_1_RTS2: E3.63, U$2.63
GP129_UART_1_RTS3: E4.63, U$4.63
GP129_UART_1_RTS4: E5.63, U$5.63
GP129_UART_1_RTS5: E6.63, U$6.63
GP129_UART_1_RTS6: E7.63, U$7.63
GP129_UART_1_RTS7: E8.63, U$8.63
GP130_UART_1_RX: E1.61, U$3.61
GP130_UART_1_RX1: E2.61, U$1.61
GP130_UART_1_RX2: E3.61, U$2.61
GP130_UART_1_RX3: E4.61, U$4.61
GP130_UART_1_RX4: E5.61, U$5.61
GP130_UART_1_RX5: E6.61, U$6.61
GP130_UART_1_RX6: E7.61, U$7.61
GP130_UART_1_RX7: E8.61, U$8.61
GP131_UART_1_TX: E1.46, U$3.46
GP131_UART_1_TX1: E2.46, U$1.46
GP131_UART_1_TX2: E3.46, U$2.46
GP131_UART_1_TX3: E4.46, U$4.46
GP131_UART_1_TX4: E5.46, U$5.46
GP131_UART_1_TX5: E6.46, U$6.46
GP131_UART_1_TX6: E7.46, U$7.46
GP131_UART_1_TX7: E8.46, U$8.46
GP134_UART_2_RX: E1.22, R6.2, U$3.22
GP134_UART_2_RX1: E2.22, R18.2, U$1.22
GP134_UART_2_RX2: E3.22, R30.2, U$2.22
GP134_UART_2_RX3: E4.22, R42.2, U$4.22
GP134_UART_2_RX4: E5.22, R54.2, U$5.22
GP134_UART_2_RX5: E6.22, R66.2, U$6.22
GP134_UART_2_RX6: E7.22, R78.2, U$7.22
GP134_UART_2_RX7: E8.22, R90.2, U$8.22
GP135_UART_2_TX: E1.27, R7.2, U$3.27
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

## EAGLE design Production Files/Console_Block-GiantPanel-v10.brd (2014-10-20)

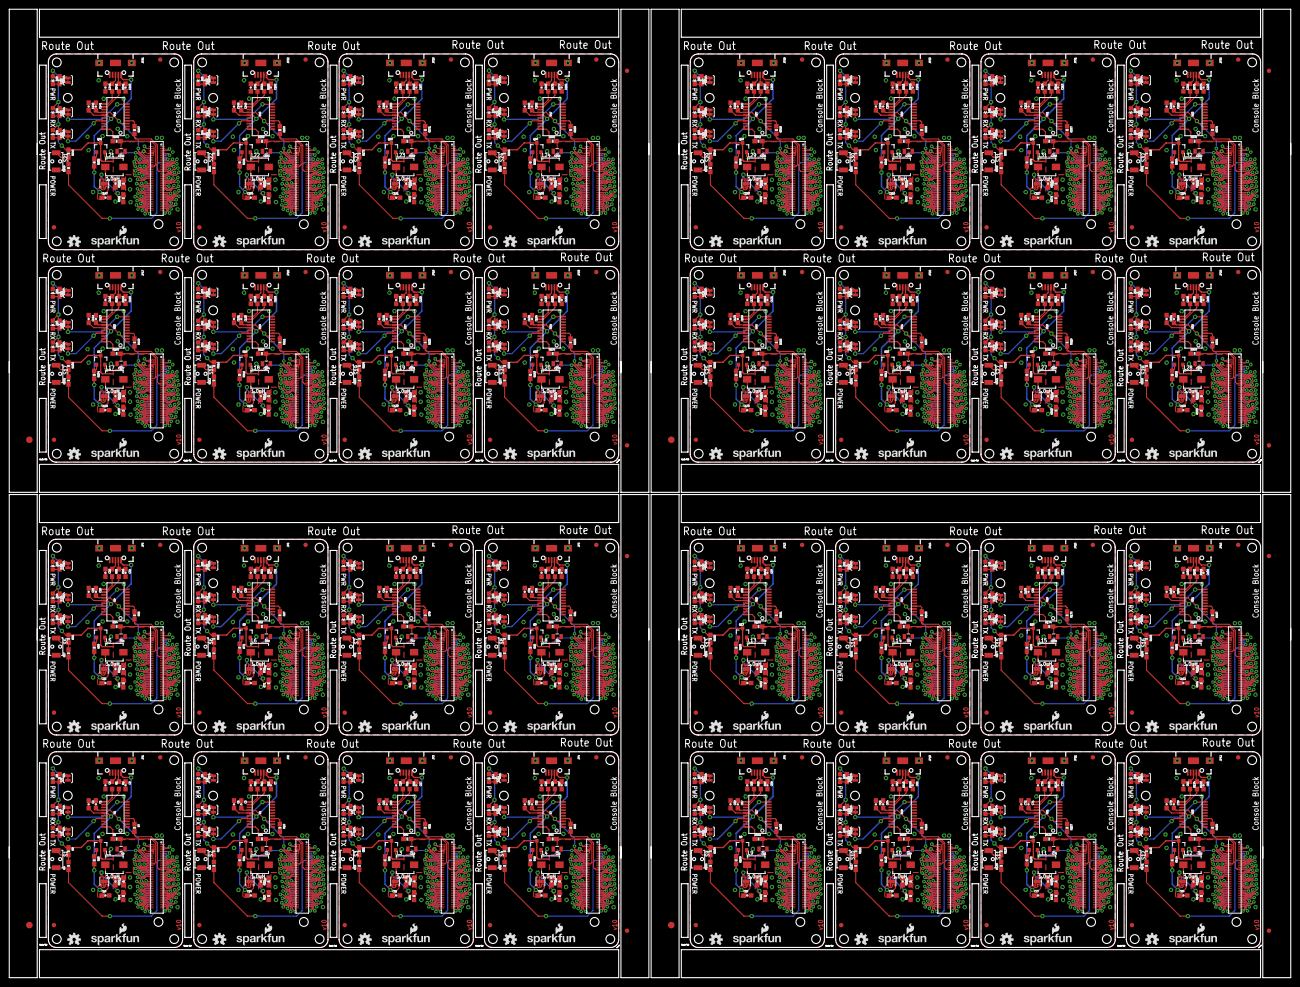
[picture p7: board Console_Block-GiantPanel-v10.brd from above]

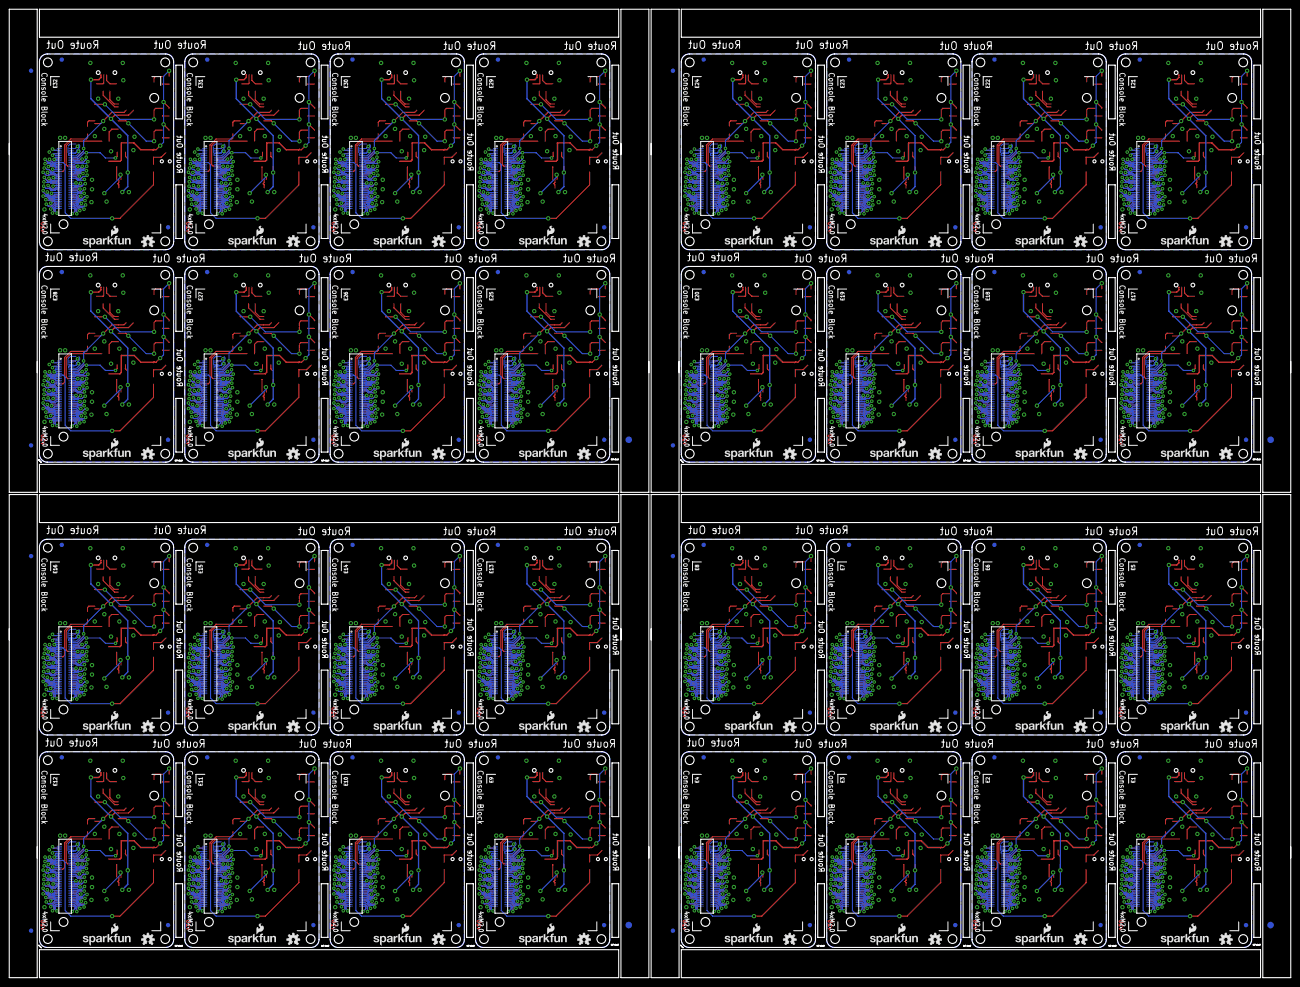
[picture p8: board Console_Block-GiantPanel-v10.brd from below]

Board: 2 copper layers, 291.1 x 220.0 mm, 1336 parts (204 on the bottom side), 2464 nets.

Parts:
C1, C2, C5, C6, C15, C16, C22, C23, C29, C30, C36, C37, C43, C44, C50, C51, C57, C58, C64, C65, C71, C72, C78, C79, C85, C86, C92, C93, C99, C100, C106, C107, C113, C114, C120, C121, C127, C128, C134, C135, C141, C142, C148, C149, C155, C156, C162, C163, C169, C170, C176, C177, C183, C184, C190, C191, C197, C198, C204, C205, C211, C212, C218, C219: 0.1uF; 0603-CAP
C3, C4, C7, C9, C11, C13, C17, C18, C20, C24, C25, C27, C31, C32, C34, C38, C39, C41, C45, C46, C48, C52, C53, C55, C59, C60, C62, C66, C67, C69, C73, C74, C76, C80, C81, C83, C87, C88, C90, C94, C95, C97, C101, C102, C104, C108, C109, C111, C115, C116, C118, C122, C123, C125, C129, C130, C132, C136, C137, C139, C143, C144, C146, C150, C151, C153, C157, C158, C160, C164, C165, C167, C171, C172, C174, C178, C179, C181, C185, C186, C188, C192, C193, C195, C199, C200, C202, C206, C207, C209, C213, C214, C216, C220, C221, C223: 47pF; 0603-CAP
C8, C12, C19, C26, C33, C40, C47, C54, C61, C68, C75, C82, C89, C96, C103, C110, C117, C124, C131, C138, C145, C152, C159, C166, C173, C180, C187, C194, C201, C208, C215, C222: 22uF; 0805
C10, C14, C21, C28, C35, C42, C49, C56, C63, C70, C77, C84, C91, C98, C105, C112, C119, C126, C133, C140, C147, C154, C161, C168, C175, C182, C189, C196, C203, C210, C217, C224: 4.7uF; 0603-CAP
D1, D4, D7, D10, D13, D16, D19, D22, D25, D28, D31, D34, D37, D40, D43, D46, D49, D52, D55, D58, D61, D64, D67, D70, D73, D76, D79, D82, D85, D88, D91, D94: RED; LED-0603
D2, D5, D8, D11, D14, D17, D20, D23, D26, D29, D32, D35, D38, D41, D44, D47, D50, D53, D56, D59, D62, D65, D68, D71, D74, D77, D80, D83, D86, D89, D92, D95: YELLOW; LED-0603
D3, D6, D9, D12, D15, D18, D21, D24, D27, D30, D33, D36, D39, D42, D45, D48, D51, D54, D57, D60, D63, D66, D69, D72, D75, D78, D81, D84, D87, D90, D93, D96: BLUE; LED-0603
E1, E2, E3, E4, E5, E6, E7, E8, E9, E10, E11, E12, E13, E14, E15, E16, E17, E18, E19, E20, E21, E22, E23, E24, E25, E26, E27, E28, E29, E30, E31, E32: EDISON_CONNECTOR_FULLMOUNTING_HOLES; EDISON_DAUGHTER
E$1, E$2, E$9, E$10, E$15, E$16, E$21, E$22: FIDUCIAL-1.5X3
E$3, E$4, E$5, E$6, E$7, E$8, E$11, E$12, E$13, E$14, E$17, E$18, E$19, E$20, E$23, E$24: FIDUCIAL-1X2
FID1, FID2, FID3, FID4, FID5, FID6, FID7, FID8, FID9, FID10, FID11, FID12, FID13, FID14, FID15, FID16, FID17, FID18, FID19, FID20, FID21, FID22, FID23, FID24, FID25, FID26, FID27, FID28, FID29, FID30, FID31, FID32, FID33, FID34, FID35, FID36, FID37, FID38, FID39, FID40, FID41, FID42, FID43, FID44, FID45, FID46, FID47, FID48, FID49, FID50, FID51, FID52, FID53, FID54, FID55, FID56, FID57, FID58, FID59, FID60, FID61, FID62, FID63, FID64, FID65, FID66, FID67, FID68, FID69, FID70, FID71, FID72, FID73, FID74, FID75, FID76, FID77, FID78, FID79, FID80, FID81, FID82, FID83, FID84, FID85, FID86, FID87, FID88, FID89, FID90, FID91, FID92, FID93, FID94, FID95, FID96, FID97, FID98, FID99, FID100, FID101, FID102, FID103, FID104, FID105, FID106, FID107, FID108, FID109, FID110, FID111, FID112, FID113, FID114, FID115, FID116, FID117, FID118, FID119, FID120, FID121, FID122, FID123, FID124, FID125, FID126, FID127, FID128: FIDUCIAL1X2; FIDUCIAL-1X2
JP1, JP2, JP3, JP4, JP5, JP6, JP7, JP8, JP9, JP10, JP11, JP12, JP13, JP14, JP15, JP16, JP17, JP18, JP19, JP20, JP21, JP22, JP23, JP24, JP25, JP26, JP27, JP28, JP29, JP30, JP31, JP32: USB_MICROB; USB-B-MICRO-SMD_V03
L1, L2, L3, L4, L5, L6, L7, L8, L9, L10, L11, L12, L13, L14, L15, L16, L17, L18, L19, L20, L21, L22, L23, L24, L25, L26, L27, L28, L29, L30, L31, L32: 1.0uH; INDUCTOR-SRP4020
LOGO1, LOGO3, LOGO6, LOGO7, LOGO10, LOGO11, LOGO14, LOGO15, LOGO18, LOGO19, LOGO22, LOGO23, LOGO26, LOGO27, LOGO30, LOGO31, LOGO34, LOGO35, LOGO38, LOGO39, LOGO42, LOGO43, LOGO46, LOGO47, LOGO50, LOGO51, LOGO54, LOGO55, LOGO58, LOGO59, LOGO62, LOGO63, LOGO66, LOGO67, LOGO70, LOGO71, LOGO74, LOGO75, LOGO78, LOGO79, LOGO82, LOGO83, LOGO86, LOGO87, LOGO90, LOGO91, LOGO94, LOGO95, LOGO98, LOGO99, LOGO102, LOGO103, LOGO106, LOGO107, LOGO110, LOGO111, LOGO114, LOGO115, LOGO118, LOGO119, LOGO122, LOGO123, LOGO126, LOGO127: SFE_LOGO_NAME_FLAME.1_INCH; SFE_LOGO_NAME_FLAME_.1
LOGO2, LOGO4, LOGO5, LOGO8, LOGO9, LOGO12, LOGO13, LOGO16, LOGO17, LOGO20, LOGO21, LOGO24, LOGO25, LOGO28, LOGO29, LOGO32, LOGO33, LOGO36, LOGO37, LOGO40, LOGO41, LOGO44, LOGO45, LOGO48, LOGO49, LOGO52, LOGO53, LOGO56, LOGO57, LOGO60, LOGO61, LOGO64, LOGO65, LOGO68, LOGO69, LOGO72, LOGO73, LOGO76, LOGO77, LOGO80, LOGO81, LOGO84, LOGO85, LOGO88, LOGO89, LOGO92, LOGO93, LOGO96, LOGO97, LOGO100, LOGO101, LOGO104, LOGO105, LOGO108, LOGO109, LOGO112, LOGO113, LOGO116, LOGO117, LOGO120, LOGO121, LOGO124, LOGO125, LOGO128: OSHW-LOGOS; OSHW-LOGO-S
Q1, Q2, Q3, Q4, Q5, Q6, Q7, Q8, Q9, Q10, Q11, Q12, Q13, Q14, Q15, Q16, Q17, Q18, Q19, Q20, Q21, Q22, Q23, Q24, Q25, Q26, Q27, Q28, Q29, Q30, Q31, Q32: BSS138; SOT23-3
R1, R2, R11, R12, R25, R26, R37, R38, R49, R50, R61, R62, R73, R74, R85, R86, R97, R98, R109, R110, R121, R122, R133, R134, R145, R146, R157, R158, R169, R170, R181, R182, R193, R194, R205, R206, R217, R218, R229, R230, R241, R242, R253, R254, R265, R266, R277, R278, R289, R290, R301, R302, R313, R314, R325, R326, R337, R338, R349, R350, R361, R362, R373, R374: 27; 0603
R3, R4, R5, R10, R15, R16, R17, R24, R27, R28, R29, R36, R39, R40, R41, R48, R51, R52, R53, R60, R63, R64, R65, R72, R75, R76, R77, R84, R87, R88, R89, R96, R99, R100, R101, R108, R111, R112, R113, R120, R123, R124, R125, R132, R135, R136, R137, R144, R147, R148, R149, R156, R159, R160, R161, R168, R171, R172, R173, R180, R183, R184, R185, R192, R195, R196, R197, R204, R207, R208, R209, R216, R219, R220, R221, R228, R231, R232, R233, R240, R243, R244, R245, R252, R255, R256, R257, R264, R267, R268, R269, R276, R279, R280, R281, R288, R291, R292, R293, R300, R303, R304, R305, R312, R315, R316, R317, R324, R327, R328, R329, R336, R339, R340, R341, R348, R351, R352, R353, R360, R363, R364, R365, R372, R375, R376, R377, R384: 1K; 0603-RES
R6, R7, R18, R19, R30, R31, R42, R43, R54, R55, R66, R67, R78, R79, R90, R91, R102, R103, R114, R115, R126, R127, R138, R139, R150, R151, R162, R163, R174, R175, R186, R187, R198, R199, R210, R211, R222, R223, R234, R235, R246, R247, R258, R259, R270, R271, R282, R283, R294, R295, R306, R307, R318, R319, R330, R331, R342, R343, R354, R355, R366, R367, R378, R379: 100; 0603-RES
R8, R20, R32, R44, R56, R68, R80, R92, R104, R116, R128, R140, R152, R164, R176, R188, R200, R212, R224, R236, R248, R260, R272, R284, R296, R308, R320, R332, R344, R356, R368, R380: 10K; 0603-RES
R9, R21, R33, R45, R57, R69, R81, R93, R105, R117, R129, R141, R153, R165, R177, R189, R201, R213, R225, R237, R249, R261, R273, R285, R297, R309, R321, R333, R345, R357, R369, R381: 22; 0603-RES
R13, R22, R34, R46, R58, R70, R82, R94, R106, R118, R130, R142, R154, R166, R178, R190, R202, R214, R226, R238, R250, R262, R274, R286, R298, R310, R322, R334, R346, R358, R370, R382: 680k; 0603-RES
R14, R23, R35, R47, R59, R71, R83, R95, R107, R119, R131, R143, R155, R167, R179, R191, R203, R215, R227, R239, R251, R263, R275, R287, R299, R311, R323, R335, R347, R359, R371, R383: 120k; 0603-RES
S1, S2, S3, S4, S5, S6, S7, S8, S9, S10, S11, S12, S13, S14, S15, S16, S17, S18, S19, S20, S21, S22, S23, S24, S25, S26, S27, S28, S29, S30, S31, S32: POWER; TACTILE_SWITCH-SMD-RIGHT-ANGLE
SJ1, SJ2, SJ3, SJ4, SJ5, SJ6, SJ7, SJ8, SJ9, SJ10, SJ11, SJ12, SJ13, SJ14, SJ15, SJ16, SJ17, SJ18, SJ19, SJ20, SJ21, SJ22, SJ23, SJ24, SJ25, SJ26, SJ27, SJ28, SJ29, SJ30, SJ31, SJ32, SJ33, SJ34, SJ35, SJ36, SJ37, SJ38, SJ39, SJ40, SJ41, SJ42, SJ43, SJ44, SJ45, SJ46, SJ47, SJ48, SJ49, SJ50, SJ51, SJ52, SJ53, SJ54, SJ55, SJ56, SJ57, SJ58, SJ59, SJ60, SJ61, SJ62, SJ63, SJ64, SJ65, SJ66, SJ67, SJ68, SJ69, SJ70, SJ71, SJ72, SJ73, SJ74, SJ75, SJ76, SJ77, SJ78, SJ79, SJ80, SJ81, SJ82, SJ83, SJ84, SJ85, SJ86, SJ87, SJ88, SJ89, SJ90, SJ91, SJ92, SJ93, SJ94, SJ95, SJ96: JUMPER-PAD-2-NC_BY_TRACE; PAD-JUMPER-2-NC_BY_TRACE_YES_SILK
U1, U2, U5, U7, U9, U11, U13, U15, U17, U19, U21, U23, U25, U27, U29, U31, U33, U35, U37, U39, U41, U43, U45, U47, U49, U51, U53, U55, U57, U59, U61, U63: FT231XS-U; SSOP20_L
U3, U4, U6, U8, U10, U12, U14, U16, U18, U20, U22, U24, U26, U28, U30, U32, U34, U36, U38, U40, U42, U44, U46, U48, U50, U52, U54, U56, U58, U60, U62, U64: TPS62065; WSON-8-PAD
U$1, U$2, U$3, U$4, U$5, U$6, U$7, U$8, U$9, U$10, U$11, U$12, U$13, U$14, U$15, U$16, U$17, U$18, U$19, U$20, U$21, U$22, U$23, U$24, U$25, U$26, U$27, U$28, U$29, U$30, U$31, U$32: EDISON_CONNECTOR_FULLHEADER; DF40C-70DP-0.4(51)

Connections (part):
1.8V: C1.2, E1.12, U2.3, U2.14, U$3.12
1.8V1: C5.2, E2.12, U1.3, U1.14, U$1.12
1.8V2: C15.2, E3.12, U5.3, U5.14, U$2.12
1.8V3: C22.2, E4.12, U7.3, U7.14, U$4.12
1.8V4: C29.2, E5.12, U9.3, U9.14, U$5.12
1.8V5: C36.2, E6.12, U11.3, U11.14, U$6.12
1.8V6: C43.2, E7.12, U13.3, U13.14, U$7.12
1.8V7: C50.2, E8.12, U15.3, U15.14, U$8.12
1.8V8: C57.2, E9.12, U17.3, U17.14, U$9.12
1.8V9: C64.2, E10.12, U19.3, U19.14, U$10.12
1.8V10: C71.2, E11.12, U21.3, U21.14, U$11.12
1.8V11: C78.2, E12.12, U23.3, U23.14, U$12.12
1.8V12: C85.2, E13.12, U25.3, U25.14, U$13.12
1.8V13: C92.2, E14.12, U27.3, U27.14, U$14.12
1.8V14: C99.2, E15.12, U29.3, U29.14, U$15.12
1.8V15: C106.2, E16.12, U31.3, U31.14, U$16.12
1.8V16: C113.2, E17.12, U33.3, U33.14, U$17.12
1.8V17: C120.2, E18.12, U35.3, U35.14, U$18.12
1.8V18: C127.2, E19.12, U37.3, U37.14, U$19.12
1.8V19: C134.2, E20.12, U39.3, U39.14, U$20.12
1.8V20: C141.2, E21.12, U41.3, U41.14, U$21.12
1.8V21: C148.2, E22.12, U43.3, U43.14, U$22.12
1.8V22: C155.2, E23.12, U45.3, U45.14, U$23.12
1.8V23: C162.2, E24.12, U47.3, U47.14, U$24.12
1.8V24: C169.2, E25.12, U49.3, U49.14, U$25.12
1.8V25: C176.2, E26.12, U51.3, U51.14, U$26.12
1.8V26: C183.2, E27.12, U53.3, U53.14, U$27.12
1.8V27: C190.2, E28.12, U55.3, U55.14, U$28.12
1.8V28: C197.2, E29.12, U57.3, U57.14, U$29.12
1.8V29: C204.2, E30.12, U59.3, U59.14, U$30.12
1.8V30: C211.2, E31.12, U61.3, U61.14, U$31.12
1.8V31: C218.2, E32.12, U63.3, U63.14, U$32.12
3.3V: E1.8, E1.10, U$3.8, U$3.10
3.3V1: E2.8, E2.10, U$1.8, U$1.10
3.3V2: E3.8, E3.10, U$2.8, U$2.10
3.3V3: E4.8, E4.10, U$4.8, U$4.10
3.3V4: E5.8, E5.10, U$5.8, U$5.10
3.3V5: E6.8, E6.10, U$6.8, U$6.10
3.3V6: E7.8, E7.10, U$7.8, U$7.10
3.3V7: E8.8, E8.10, U$8.8, U$8.10
3.3V8: E9.8, E9.10, U$9.8, U$9.10
3.3V9: E10.8, E10.10, U$10.8, U$10.10
3.3V10: E11.8, E11.10, U$11.8, U$11.10
3.3V11: E12.8, E12.10, U$12.8, U$12.10
3.3V12: E13.8, E13.10, U$13.8, U$13.10
3.3V13: E14.8, E14.10, U$14.8, U$14.10
3.3V14: E15.8, E15.10, U$15.8, U$15.10
3.3V15: E16.8, E16.10, U$16.8, U$16.10
3.3V16: E17.8, E17.10, U$17.8, U$17.10
3.3V17: E18.8, E18.10, U$18.8, U$18.10
3.3V18: E19.8, E19.10, U$19.8, U$19.10
3.3V19: E20.8, E20.10, U$20.8, U$20.10
3.3V20: E21.8, E21.10, U$21.8, U$21.10
3.3V21: E22.8, E22.10, U$22.8, U$22.10
3.3V22: E23.8, E23.10, U$23.8, U$23.10
3.3V23: E24.8, E24.10, U$24.8, U$24.10
3.3V24: E25.8, E25.10, U$25.8, U$25.10
3.3V25: E26.8, E26.10, U$26.8, U$26.10
3.3V26: E27.8, E27.10, U$27.8, U$27.10
3.3V27: E28.8, E28.10, U$28.8, U$28.10
3.3V28: E29.8, E29.10, U$29.8, U$29.10
3.3V29: E30.8, E30.10, U$30.8, U$30.10
3.3V30: E31.8, E31.10, U$31.8, U$31.10
3.3V31: E32.8, E32.10, U$32.8, U$32.10
5V: C2.2, C10.1, JP1.VBUS1, R10.2, U2.15, U4.5, U4.7, U4.8
5V1: C6.2, C14.1, JP2.VBUS1, R24.2, U1.15, U3.5, U3.7, U3.8
5V2: C16.2, C21.1, JP3.VBUS1, R36.2, U5.15, U6.5, U6.7, U6.8
5V3: C23.2, C28.1, JP4.VBUS1, R48.2, U7.15, U8.5, U8.7, U8.8
5V4: C30.2, C35.1, JP5.VBUS1, R60.2, U9.15, U10.5, U10.7, U10.8
5V5: C37.2, C42.1, JP6.VBUS1, R72.2, U11.15, U12.5, U12.7, U12.8
5V6: C44.2, C49.1, JP7.VBUS1, R84.2, U13.15, U14.5, U14.7, U14.8
5V7: C51.2, C56.1, JP8.VBUS1, R96.2, U15.15, U16.5, U16.7, U16.8
5V8: C58.2, C63.1, JP9.VBUS1, R108.2, U17.15, U18.5, U18.7, U18.8
5V9: C65.2, C70.1, JP10.VBUS1, R120.2, U19.15, U20.5, U20.7, U20.8
5V10: C72.2, C77.1, JP11.VBUS1, R132.2, U21.15, U22.5, U22.7, U22.8
5V11: C79.2, C84.1, JP12.VBUS1, R144.2, U23.15, U24.5, U24.7, U24.8
5V12: C86.2, C91.1, JP13.VBUS1, R156.2, U25.15, U26.5, U26.7, U26.8
5V13: C93.2, C98.1, JP14.VBUS1, R168.2, U27.15, U28.5, U28.7, U28.8
5V14: C100.2, C105.1, JP15.VBUS1, R180.2, U29.15, U30.5, U30.7, U30.8
5V15: C107.2, C112.1, JP16.VBUS1, R192.2, U31.15, U32.5, U32.7, U32.8
5V16: C114.2, C119.1, JP17.VBUS1, R204.2, U33.15, U34.5, U34.7, U34.8
5V17: C121.2, C126.1, JP18.VBUS1, R216.2, U35.15, U36.5, U36.7, U36.8
5V18: C128.2, C133.1, JP19.VBUS1, R228.2, U37.15, U38.5, U38.7, U38.8
5V19: C135.2, C140.1, JP20.VBUS1, R240.2, U39.15, U40.5, U40.7, U40.8
5V20: C142.2, C147.1, JP21.VBUS1, R252.2, U41.15, U42.5, U42.7, U42.8
5V21: C149.2, C154.1, JP22.VBUS1, R264.2, U43.15, U44.5, U44.7, U44.8
5V22: C156.2, C161.1, JP23.VBUS1, R276.2, U45.15, U46.5, U46.7, U46.8
5V23: C163.2, C168.1, JP24.VBUS1, R288.2, U47.15, U48.5, U48.7, U48.8
5V24: C170.2, C175.1, JP25.VBUS1, R300.2, U49.15, U50.5, U50.7, U50.8
5V25: C177.2, C182.1, JP26.VBUS1, R312.2, U51.15, U52.5, U52.7, U52.8
5V26: C184.2, C189.1, JP27.VBUS1, R324.2, U53.15, U54.5, U54.7, U54.8
5V27: C191.2, C196.1, JP28.VBUS1, R336.2, U55.15, U56.5, U56.7, U56.8
5V28: C198.2, C203.1, JP29.VBUS1, R348.2, U57.15, U58.5, U58.7, U58.8
5V29: C205.2, C210.1, JP30.VBUS1, R360.2, U59.15, U60.5, U60.7, U60.8
5V30: C212.2, C217.1, JP31.VBUS1, R372.2, U61.15, U62.5, U62.7, U62.8
5V31: C219.2, C224.1, JP32.VBUS1, R384.2, U63.15, U64.5, U64.7, U64.8
DCIN: E1.14, Q1.2, U$3.14
DCIN1: E2.14, Q2.2, U$1.14
DCIN2: E3.14, Q3.2, U$2.14
DCIN3: E4.14, Q4.2, U$4.14
DCIN4: E5.14, Q5.2, U$5.14
DCIN5: E6.14, Q6.2, U$6.14
DCIN6: E7.14, Q7.2, U$7.14
DCIN7: E8.14, Q8.2, U$8.14
DCIN8: E9.14, Q9.2, U$9.14
DCIN9: E10.14, Q10.2, U$10.14
DCIN10: E11.14, Q11.2, U$11.14
DCIN11: E12.14, Q12.2, U$12.14
DCIN12: E13.14, Q13.2, U$13.14
DCIN13: E14.14, Q14.2, U$14.14
DCIN14: E15.14, Q15.2, U$15.14
DCIN15: E16.14, Q16.2, U$16.14
DCIN16: E17.14, Q17.2, U$17.14
DCIN17: E18.14, Q18.2, U$18.14
DCIN18: E19.14, Q19.2, U$19.14
DCIN19: E20.14, Q20.2, U$20.14
DCIN20: E21.14, Q21.2, U$21.14
DCIN21: E22.14, Q22.2, U$22.14
DCIN22: E23.14, Q23.2, U$23.14
DCIN23: E24.14, Q24.2, U$24.14
DCIN24: E25.14, Q25.2, U$25.14
DCIN25: E26.14, Q26.2, U$26.14
DCIN26: E27.14, Q27.2, U$27.14
DCIN27: E28.14, Q28.2, U$28.14
DCIN28: E29.14, Q29.2, U$29.14
DCIN29: E30.14, Q30.2, U$30.14
DCIN30: E31.14, Q31.2, U$31.14
DCIN31: E32.14, Q32.2, U$32.14
FAULT: E1.19, U$3.19
FAULT1: E2.19, U$1.19
FAULT2: E3.19, U$2.19
FAULT3: E4.19, U$4.19
FAULT4: E5.19, U$5.19
FAULT5: E6.19, U$6.19
FAULT6: E7.19, U$7.19
FAULT7: E8.19, U$8.19
FAULT8: E9.19, U$9.19
FAULT9: E10.19, U$10.19
FAULT10: E11.19, U$11.19
FAULT11: E12.19, U$12.19
FAULT12: E13.19, U$13.19
FAULT13: E14.19, U$14.19
FAULT14: E15.19, U$15.19
FAULT15: E16.19, U$16.19
FAULT16: E17.19, U$17.19
FAULT17: E18.19, U$18.19
FAULT18: E19.19, U$19.19
FAULT19: E20.19, U$20.19
FAULT20: E21.19, U$21.19
FAULT21: E22.19, U$22.19
FAULT22: E23.19, U$23.19
FAULT23: E24.19, U$24.19
FAULT24: E25.19, U$25.19
FAULT25: E26.19, U$26.19
FAULT26: E27.19, U$27.19
FAULT27: E28.19, U$28.19
FAULT28: E29.19, U$29.19
FAULT29: E30.19, U$30.19
FAULT30: E31.19, U$31.19
FAULT31: E32.19, U$32.19
FW_RCVR: E1.69, U$3.69
FW_RCVR1: E2.69, U$1.69
FW_RCVR2: E3.69, U$2.69
FW_RCVR3: E4.69, U$4.69
FW_RCVR4: E5.69, U$5.69
FW_RCVR5: E6.69, U$6.69
FW_RCVR6: E7.69, U$7.69
FW_RCVR7: E8.69, U$8.69
FW_RCVR8: E9.69, U$9.69
FW_RCVR9: E10.69, U$10.69
FW_RCVR10: E11.69, U$11.69
FW_RCVR11: E12.69, U$12.69
FW_RCVR12: E13.69, U$13.69
FW_RCVR13: E14.69, U$14.69
FW_RCVR14: E15.69, U$15.69
FW_RCVR15: E16.69, U$16.69
FW_RCVR16: E17.69, U$17.69
FW_RCVR17: E18.69, U$18.69
FW_RCVR18: E19.69, U$19.69
FW_RCVR19: E20.69, U$20.69
FW_RCVR20: E21.69, U$21.69
FW_RCVR21: E22.69, U$22.69
FW_RCVR22: E23.69, U$23.69
FW_RCVR23: E24.69, U$24.69
FW_RCVR24: E25.69, U$25.69
FW_RCVR25: E26.69, U$26.69
FW_RCVR26: E27.69, U$27.69
FW_RCVR27: E28.69, U$28.69
FW_RCVR28: E29.69, U$29.69
FW_RCVR29: E30.69, U$30.69
FW_RCVR30: E31.69, U$31.69
FW_RCVR31: E32.69, U$32.69
GND: C1.1, C2.1, C3.2, C4.2, C8.2, C10.2, E1.1, E1.5, E1.9, E1.11, E1.13, E1.15, JP1.GND1, JP1.SHIELD1, JP1.SHIELD2, JP1.SHIELD3, R14.1, S1.2, SJ3.1, U2.6, U2.16, U4.1, U4.3, U4.6, U4.PAD, U$3.1, U$3.5, U$3.9, U$3.11, U$3.13, U$3.15
GND1: C5.1, C6.1, C7.2, C11.2, C12.2, C14.2, E2.1, E2.5, E2.9, E2.11, E2.13, E2.15, JP2.GND1, JP2.SHIELD1, JP2.SHIELD2, JP2.SHIELD3, R23.1, S2.2, SJ6.1, U1.6, U1.16, U3.1, U3.3, U3.6, U3.PAD, U$1.1, U$1.5, U$1.9, U$1.11, U$1.13, U$1.15
GND2: C15.1, C16.1, C17.2, C18.2, C19.2, C21.2, E3.1, E3.5, E3.9, E3.11, E3.13, E3.15, JP3.GND1, JP3.SHIELD1, JP3.SHIELD2, JP3.SHIELD3, R35.1, S3.2, SJ9.1, U5.6, U5.16, U6.1, U6.3, U6.6, U6.PAD, U$2.1, U$2.5, U$2.9, U$2.11, U$2.13, U$2.15
GND3: C22.1, C23.1, C24.2, C25.2, C26.2, C28.2, E4.1, E4.5, E4.9, E4.11, E4.13, E4.15, JP4.GND1, JP4.SHIELD1, JP4.SHIELD2, JP4.SHIELD3, R47.1, S4.2, SJ12.1, U7.6, U7.16, U8.1, U8.3, U8.6, U8.PAD, U$4.1, U$4.5, U$4.9, U$4.11, U$4.13, U$4.15
GND4: C29.1, C30.1, C31.2, C32.2, C33.2, C35.2, E5.1, E5.5, E5.9, E5.11, E5.13, E5.15, JP5.GND1, JP5.SHIELD1, JP5.SHIELD2, JP5.SHIELD3, R59.1, S5.2, SJ15.1, U9.6, U9.16, U10.1, U10.3, U10.6, U10.PAD, U$5.1, U$5.5, U$5.9, U$5.11, U$5.13, U$5.15
GND5: C36.1, C37.1, C38.2, C39.2, C40.2, C42.2, E6.1, E6.5, E6.9, E6.11, E6.13, E6.15, JP6.GND1, JP6.SHIELD1, JP6.SHIELD2, JP6.SHIELD3, R71.1, S6.2, SJ18.1, U11.6, U11.16, U12.1, U12.3, U12.6, U12.PAD, U$6.1, U$6.5, U$6.9, U$6.11, U$6.13, U$6.15
GND6: C43.1, C44.1, C45.2, C46.2, C47.2, C49.2, E7.1, E7.5, E7.9, E7.11, E7.13, E7.15, JP7.GND1, JP7.SHIELD1, JP7.SHIELD2, JP7.SHIELD3, R83.1, S7.2, SJ21.1, U13.6, U13.16, U14.1, U14.3, U14.6, U14.PAD, U$7.1, U$7.5, U$7.9, U$7.11, U$7.13, U$7.15
GND7: C50.1, C51.1, C52.2, C53.2, C54.2, C56.2, E8.1, E8.5, E8.9, E8.11, E8.13, E8.15, JP8.GND1, JP8.SHIELD1, JP8.SHIELD2, JP8.SHIELD3, R95.1, S8.2, SJ24.1, U15.6, U15.16, U16.1, U16.3, U16.6, U16.PAD, U$8.1, U$8.5, U$8.9, U$8.11, U$8.13, U$8.15
GND8: C57.1, C58.1, C59.2, C60.2, C61.2, C63.2, E9.1, E9.5, E9.9, E9.11, E9.13, E9.15, JP9.GND1, JP9.SHIELD1, JP9.SHIELD2, JP9.SHIELD3, R107.1, S9.2, SJ27.1, U17.6, U17.16, U18.1, U18.3, U18.6, U18.PAD, U$9.1, U$9.5, U$9.9, U$9.11, U$9.13, U$9.15
GND9: C64.1, C65.1, C66.2, C67.2, C68.2, C70.2, E10.1, E10.5, E10.9, E10.11, E10.13, E10.15, JP10.GND1, JP10.SHIELD1, JP10.SHIELD2, JP10.SHIELD3, R119.1, S10.2, SJ30.1, U19.6, U19.16, U20.1, U20.3, U20.6, U20.PAD, U$10.1, U$10.5, U$10.9, U$10.11, U$10.13, U$10.15
GND10: C71.1, C72.1, C73.2, C74.2, C75.2, C77.2, E11.1, E11.5, E11.9, E11.11, E11.13, E11.15, JP11.GND1, JP11.SHIELD1, JP11.SHIELD2, JP11.SHIELD3, R131.1, S11.2, SJ33.1, U21.6, U21.16, U22.1, U22.3, U22.6, U22.PAD, U$11.1, U$11.5, U$11.9, U$11.11, U$11.13, U$11.15
GND11: C78.1, C79.1, C80.2, C81.2, C82.2, C84.2, E12.1, E12.5, E12.9, E12.11, E12.13, E12.15, JP12.GND1, JP12.SHIELD1, JP12.SHIELD2, JP12.SHIELD3, R143.1, S12.2, SJ36.1, U23.6, U23.16, U24.1, U24.3, U24.6, U24.PAD, U$12.1, U$12.5, U$12.9, U$12.11, U$12.13, U$12.15
GND12: C85.1, C86.1, C87.2, C88.2, C89.2, C91.2, E13.1, E13.5, E13.9, E13.11, E13.13, E13.15, JP13.GND1, JP13.SHIELD1, JP13.SHIELD2, JP13.SHIELD3, R155.1, S13.2, SJ39.1, U25.6, U25.16, U26.1, U26.3, U26.6, U26.PAD, U$13.1, U$13.5, U$13.9, U$13.11, U$13.13, U$13.15
GND13: C92.1, C93.1, C94.2, C95.2, C96.2, C98.2, E14.1, E14.5, E14.9, E14.11, E14.13, E14.15, JP14.GND1, JP14.SHIELD1, JP14.SHIELD2, JP14.SHIELD3, R167.1, S14.2, SJ42.1, U27.6, U27.16, U28.1, U28.3, U28.6, U28.PAD, U$14.1, U$14.5, U$14.9, U$14.11, U$14.13, U$14.15
GND14: C99.1, C100.1, C101.2, C102.2, C103.2, C105.2, E15.1, E15.5, E15.9, E15.11, E15.13, E15.15, JP15.GND1, JP15.SHIELD1, JP15.SHIELD2, JP15.SHIELD3, R179.1, S15.2, SJ45.1, U29.6, U29.16, U30.1, U30.3, U30.6, U30.PAD, U$15.1, U$15.5, U$15.9, U$15.11, U$15.13, U$15.15
GND15: C106.1, C107.1, C108.2, C109.2, C110.2, C112.2, E16.1, E16.5, E16.9, E16.11, E16.13, E16.15, JP16.GND1, JP16.SHIELD1, JP16.SHIELD2, JP16.SHIELD3, R191.1, S16.2, SJ48.1, U31.6, U31.16, U32.1, U32.3, U32.6, U32.PAD, U$16.1, U$16.5, U$16.9, U$16.11, U$16.13, U$16.15
GND16: C113.1, C114.1, C115.2, C116.2, C117.2, C119.2, E17.1, E17.5, E17.9, E17.11, E17.13, E17.15, JP17.GND1, JP17.SHIELD1, JP17.SHIELD2, JP17.SHIELD3, R203.1, S17.2, SJ51.1, U33.6, U33.16, U34.1, U34.3, U34.6, U34.PAD, U$17.1, U$17.5, U$17.9, U$17.11, U$17.13, U$17.15
GND17: C120.1, C121.1, C122.2, C123.2, C124.2, C126.2, E18.1, E18.5, E18.9, E18.11, E18.13, E18.15, JP18.GND1, JP18.SHIELD1, JP18.SHIELD2, JP18.SHIELD3, R215.1, S18.2, SJ54.1, U35.6, U35.16, U36.1, U36.3, U36.6, U36.PAD, U$18.1, U$18.5, U$18.9, U$18.11, U$18.13, U$18.15
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

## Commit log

2014-08-08 added layout for Console board. Ready for review
    [Edzzanine_Console.brd, Edzzanine_Console.sch]
2014-08-08 replaced power supply with something more powerful. added fiducials
    [Edzzanine_Console.brd, Edzzanine_Console.sch]
2014-08-09 added vias to usb connectors for better staking.
    [Edzzanine_Console.brd]
2014-08-12 removed stray trace
    [Edzzanine_Console.brd]
2014-08-12 removed Edzzanine from name
    [Edzzanine_Console.brd]
2014-08-25 changes to cap value
    [Edzzanine_Console.brd, Edzzanine_Console.sch]
2014-09-22 Added DCIN enable circuit replaced power button with new side shooting SMD switch Fixed dimensions corrected ground planes to not include orphans corrected name of board added DCIN pin
    [Edzzanine_Console.brd, Edzzanine_Console.sch]
2014-09-22 corrected save issue
    [Edzzanine_Console.brd]
2014-09-23 changed names of files, removed .epf
    [Console_Block.brd, Console_Block.sch]
2014-09-25 file cleanup
    [Console_Block.brd, Console_Block.sch]
2014-10-16 changed rev number to v01 replaced ouput capacitor on vreg to 22uF replaced filter capacitor on vreg to 47pf replaced connector footprints to add T/Brestrict to prevent solder bridging
    [Console_Block.brd, Console_Block.sch]
2014-10-16 fixed bridging
    [Console_Block.brd, Console_Block.sch]
2014-10-16 added ground vias to solidify ground planes. also added staking vias for USB connectors.
    [Console_Block.brd]
2014-10-16 Add a couple vias near FTDI for gnd
    [Console_Block.brd, Console_Block.sch]
2014-10-17 fixed footprint
    [Console_Block.brd, Console_Block.sch]
2014-10-17 removed stray Bplace from Package
    [Console_Block.brd, Console_Block.sch]
2014-10-17 Ready for reds Tweaked silk positions, add some restrict between pads on QFN No known to-do items
    [Console_Block.brd, Console_Block.sch]
2014-10-20 added bottom side fiducials
    [Console_Block.brd, Console_Block.sch]
2014-10-20 created panel v10
    [Console_Block-Panel-v10.brd]
2014-10-20 created giant panel
    [Console_Block-GiantPanel-v10.brd]
2014-10-20 corrected jumper on QFN package
    [Console_Block.brd]
2014-10-20 fixed thermal tick on panels
    [Console_Block-GiantPanel-v10.brd, Console_Block-Panel-v10.brd]

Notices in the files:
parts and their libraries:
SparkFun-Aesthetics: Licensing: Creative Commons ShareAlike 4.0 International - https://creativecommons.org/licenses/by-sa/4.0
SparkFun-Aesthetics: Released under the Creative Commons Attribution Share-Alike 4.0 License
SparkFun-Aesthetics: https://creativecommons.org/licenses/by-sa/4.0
